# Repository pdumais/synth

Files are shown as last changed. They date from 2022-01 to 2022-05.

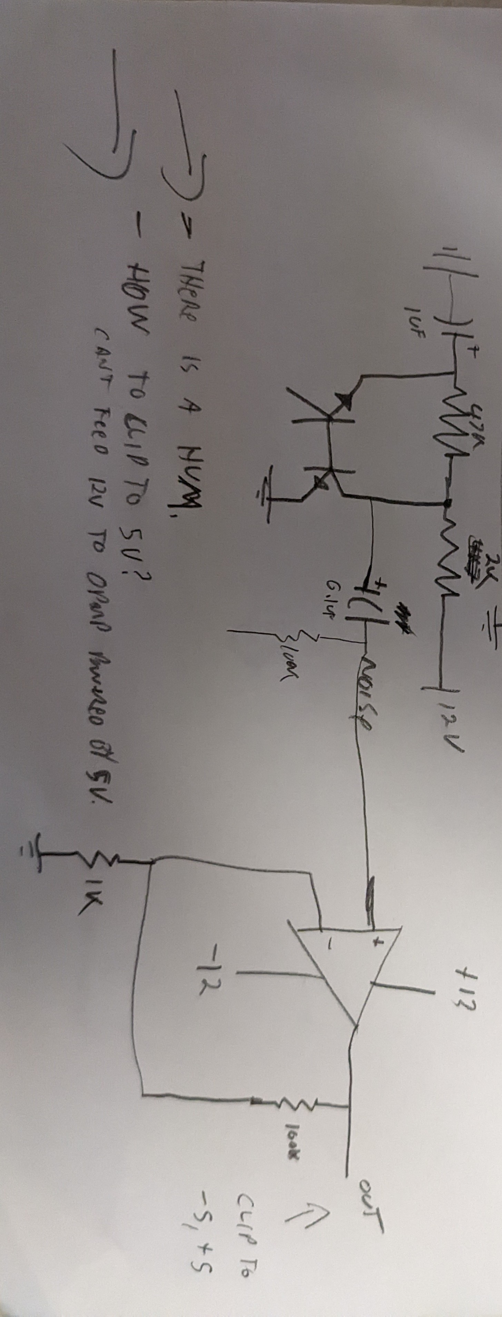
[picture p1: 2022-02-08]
modules/noise/design.jpg

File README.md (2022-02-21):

# Modular Synthesizer

# Design
- 5V system, but requires +12,-12 rails for modules using opamps
- uses computer PSU
- 2 signal paths:
    1) The audio signal. -5 - +5V. 
    2) Control Voltages. They work on unipolar 5V.

# Current modules
- [dual VCO and quad LFO. Square only](modules/osc)
- [LFO shaper: to convert square to trianble/sine or anything in between](modules/waveshaper)
- [Sequencer](modules/sequencer)
- [Clock](modules/clock)
- [Clock Divider](modules/divider)
- [Voltage Controlled Resistors](modules/digipot)
- [Midi2CV](modules/midi2cv)
- [Noise Generator](modules/noise)
- [4 Channel VCA](modules/vca)
- [4 stage VCF](modules/vcf)

# Known issues
- Power filtering
    The oscilloscope shows that the -5 and +5 rails oscillate at an amplitude of 0.4v. The wave has a period of 500ns.
    That's 2mhz. 
    For the CV path, this gets filtered out by the sampling rate of the ADC, so no need to do anything about it. When CV
    is used with analog, it wouldn't be audible anyway.

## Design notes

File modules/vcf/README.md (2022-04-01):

Based on the as3320.

- The range for cutoff frequency CV is +-6V. What does that relate to?
    18mV per octave. they say to use a range from -25 to 155 
    this is a range of 180mV, so 10 octaves. if we stay above 0, we loose
    the last 1.5 octave since increasing voltage lowers the.cutoff

    the 100k and 1.8k resistors on the cv input in the datasheet are a divider
    to drop 10v down to 180mV. I need to adapt this for 5v

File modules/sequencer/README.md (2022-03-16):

# UPDATE
This turns out to be a not so good design.
The stepper and the binary counter are out of sink, so the step number being displayed is not accurate. I suspect
that this is happening because of a difference in startup time betewen both chips, so one chip misses
a clock while the other has processed one already.

But the sequencing part of it does work. So It's a good prototype.

# Design
This is a 8 step sequencer based on the 4017 counter. 

The 4017's Q1 to Q8 outputs go through 8 optentiometers which are all connected to unity gain opamp. The opamp is used to limit the current draw from the system after going out on the CV output

I had a lot of help from this thread: https://www.modwiggler.com/forum/viewtopic.php?t=258437
I'm not sure why having all pots connected together with a 100K resistor doesn't create a voltage divider. It used to create
on and it was a problem. But by connecting everything the the inverting amplifier at the end, it solved that problem. 
At the time of writing this, I don't understand why.

What I didn't like about popular designs that I saw, was that they were all using diodes. The voltage drop of the diode would 
affect the CV by a great margin IMO. With my design, I don't get any voltage drops so CV should be quite accurate. 

## Keeping it simple
As I was designing this module, I realized how many more features I could add to it but it would become increasingly difficult and
more expensive to do so. I realized that I would be much better off to build it with a microcontroller instead. But I decided
to keep using the 4017 because it was an interesting design. 
These are the things I would've liked to do, but decided to hold off until I build a full digital sequencer. The following list 
is more like personal notes so that I can remember later why I didn't implement those.
- A pause button: This sounds simple because all I have to do is inhibit the clock on the 4017 and on the 4163. But both chips
  expect a high and low signal respectively. So I would need a NOT gate for one of them. But then I also need to inhibit the clock
  out of the gate and actually keep that signal high. Instead of using a NOT gate on one of the ic, I could simply cut the clock source.
  but then I would need to tie both ic's clk pins to ground. If I leave it high, I risk creating a rising edge so the pause would 
  force a move to the next step and then pause. So I need to ground the clock signal for the whole circuit, but raise the gate signal.
  it's getting a bit complicated
- Randomizer:To be able to randomly shuffle steps. That's just not something you can do with the 4017.
- variable step length: it would be possible to create the circuitry to manipulate the clock entering the 4017 and multiply/divide 
  for every step. But that's a lot more components to add and becomes more expensive. This is something that is just easier with a 
  microcontroller

## 74163 binary counter
NOTE: This is no longer in the design. Because the 74163 starts with all outputs high and goes to 0 after the first clock
      That's out of sync with the 4017. So I removed that. It could've worked with the 74161 maybe.

The 74163 (4 bit binary counter) is used to control the daisy chaining. QD will be low for the first 8 clocks and then high 
for the next 8 clocks. This is used to control which of the 2 sequencers are active when daisy chained. there are 6 pins that 
require a jumper to control the daisy-chain operation 
    - A jumper between pin 1&2 will make the 4017 active  (by controlling the vcc line) when 4163.QD is high, 
      so during steps 9-16. This is the setting required for the second sequencer
    - A jumper between pin 3&4 will make the 4017 active  (by controlling the vcc line) when 4163.QD is 
      low, so during steps 1-8. This is the setting required for the first sequencer
    - A jumper between pin 5&6 will make the 4017 active  (by controlling the vcc line) all the time, 
      bypassing the 4163 logic. This is the setting required when running a standalone sequencer (8 steps only)
 
Note that both sequencers run their own 4163, so it is possible to configure them in a conflicting manner.

When daisy-chaining, a cable needs to be connected between both sequencers so that:
    - the reset line is connected between both sequencers so that pressing the reset button will act on both sequencers
    - the enable line is connected between both sequencers so that pressing the start/stop button will act on both sequencers

## Gate
The gate signal is fed to a monostable multivibrator that generates a gate signal at the same frequency than the input clock. The pulse width cn be adjusted
beteen 160ms to 1.8s through a 10k potentionmeter

## Inputs / Outputs
### Inputs
    - Clock in
    - Buttons to shorten the sequence to 2 or 4 steps. 
    - Power: +12, -12, +5, Ground 
    - 8 pins for potentiometers wipers, 8 pins for their input voltage from the 4017, 1 pin for their ground
### Outputs
    - CV
    - Gate

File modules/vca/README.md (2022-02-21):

# Voltage Controlled Amplifier

This is based on the AS2164 ic.
    - Unity gain at 5V and -80dB at 0V

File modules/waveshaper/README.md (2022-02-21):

# Wave shaper
Converts a square wave to a triangle or sine or anything in between
Only works for LFOs (below 25hz)
Requires 4 variable resistances (4-gang potentiometer, or digipots)
    Adjusting the resistance will adjust the shape of the wave. 
    If the frequency changes, the shape needs to be reajusted everytime

Can work with audio unipolar signal too. Using a 1uF capacitor with a 10k pot, I we get a sine:
    at 20hz with 10 kOhms
    at 2khz with 100 Ohms
    at 10khz with 20 Ohms

# Inputs
- signal
- 4 variable resistors

# Outputs
- signal

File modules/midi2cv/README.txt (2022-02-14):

The board is programmed through the serial port pins with an FTDI cable. Not through the USB port
    There is a FTDI header on the shield

To test with vkeybd:
    vkeybd --addr 24:0
    The address is the combination of client:port as per /proc/asound/seq/clients
    Testing sysex: amidi -p hw:2,0,0 -S "F0 00 00 <d1> <d2> <d3> F7"

software
	sysex:
		Can be tested with: amidi -p hw:2,0,0 -S "F0 00 00 <d1> <d2> <d3> F7"
		Set channel to listen to for pitch CV 1
			d1 = 0x10
			d2 = CV number (0..2)
			d3 = channel (0..16)
		Set channel to listen to for CC CV 1
			d1 = 0x20
			d2 = CC number (0..2)
			d3 = channel (0..16)
		Set CC number to listen to for CC CV 1
			d1 = 0x30
			d2 = CC number (0..2)
			d3 = CC number (0..255)
		Set output clock pulse width 
			d1 = 0x40
			d2 = width in ms. 5..255
	 	Write config to EEPROM	
			d1 = 0x55
			d2 = 0x55
			d3 = 0x55

hardware
    panel-mount din5
    ftdi programmer

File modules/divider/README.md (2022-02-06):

# Divider
This modules takes a clock input and outputs a version of the same clock divided by 8. So 8hz becomes 1hz.
Square wave only. 5v

There is also a Gate output that can be configured with a different pulse width. The jumpers on on 14pin headers
can be connected in a way to generate a 1/8 pulse width, 2/8 pulse width ... to 7/8 pulse width.
For example, if jumpers are set on 1&2, 3&4, 5&6 and an input clock of 8hz is fed in, the gate will output a 1hz clock
where the first 3/8 of the cycle will be high, and the last 5/8 will be low.

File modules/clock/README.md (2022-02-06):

# Clock module
A rotary encoder connected to the module will set the clock to a BPM from 30 to 240. 
1 square wave output on the CLK pin, and another one, 8 times faster, on the clk8 output.

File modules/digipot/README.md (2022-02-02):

This is a CV to resistance converter. It takes a CV signal of 0-5V and sets 8 digital resistors to that value

- CV input is read through a 10bit ADC but digipots are 8 bits.
- each resistor can be configured from 0 to 10k in 39 Ohm increments

- NOTE: This board has not been tested yet. Need to:
    print it and check if all component fits
    make sure pins for all chips are properly connected

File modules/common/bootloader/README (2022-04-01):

Burning bootloader:
    connect stk500 and chip each on their own power supply. Leave the VCC pin disconnected from the ISP header
    
    avrdude  -c stk500 -pm1284p -P /dev/ttyUSB9 -b115200 -B300 -U lfuse:w:0xF7:m -U hfuse:w:0xDE:m
    avrdude  -c stk500 -pm1284p -P /dev/ttyUSB9 -b115200 -B300 -U flash:w:optiboot_atmega1284p.hex:i

The, using FTDI:
avrdude -vvv -pm1284p -P /dev/ttyUSB10 -carduino -b115200 -U flash:w:firmware.hex:i

    avrdude  -c stk500 -pm32 -P /dev/ttyUSB9 -b115200 -B300 -U lfuse:w:0xA4:m -U hfuse:w:0x90:m
    avrdude  -c stk500 -pm32 -P /dev/ttyUSB9 -b115200 -B300 -U flash:w:optiboot_flash_atmega32_UART0_115200_8000000L_B0.hex:i

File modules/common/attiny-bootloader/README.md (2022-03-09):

Optiboot Bootloader
This core includes an Optiboot bootloader for the ATtiny84/44, operating using software serial at 19200 baud - the software serial uses the AIN0 and AIN1 pins (see UART section below). The bootloader uses 640b of space, leaving 3456 or7552b available for user code. In order to work on the 84, which does not have hardware bootloader support (hence no BOOTRST functionality), "Virtual Boot" is used. This works around this limitation by rewriting the vector table of the sketch as it's uploaded - the reset vector gets pointed at the start of the bootloader, while the EE_RDY vector gets pointed to the start of the application.

Programming the ATtiny84/44 via ISP without the bootloader is fully supported; the 24 is supported only for ISP programming

Wiring for uploading with optiboot
    Gnd of serial adapter to Gnd of target
    Vcc of serial adapter to Gnd of target (many adapters have a switch to select the voltage)
    Tx of serial adapter to Rx of target
    Rx of serial adapter to Tx of target
    DTR of serial adapter to DTR of target, or if using self-build board, the other side of the 0.1uF autoreset capacitor

Wiring for ISP
    Vcc of programmer to Vcc of target
    Gnd of programmer to Gnd of target
    SCK of programmer (pin 13 on Uno/Nano/ProMini) to SCK of target
    MISO of programmer (pin 12 on Uno/Nano/ProMini) to MISO of target
    MOSI of programmer (pin 11 on Uno/Nano/ProMini) to MOSI of target

avrdude  -c stk500 -v -v -pt44 -P /dev/ttyUSB10 -B8 -U lfuse:w:0xE2:m -U hfuse:w:0xDC:m -U efuse:w:0xFE:m
avrdude  -c stk500 -v -v -pt44 -P /dev/ttyUSB10 -B8 -U flash:w:optiboot_attiny44_8000000L.hex:i

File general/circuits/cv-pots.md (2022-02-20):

The first circuit in the diagram can be used to to mix a CV with a potentiometer value and attenuate the result.
This is useful when wanting to use CV and knob at the same time.

The second circuit is used to disable the potentiometer when the CV signal is connected. The resistor is used to protect
the circuit when the jack is being plugged in and the pot is at 0%. There would be a small time when the top would touch
the switch and the signal would flow to the potentiometer.

The third circuit creates an average of both inputs. So the following can happen:
	pot at 0v, CV at 0v: 0v
	pot at 0v, CV at 5v: 2.5v
	pot at 5v, CV at 0v: 2.5v
	pot at 5v, CV at 5v: 5v

So connecting the jack would only allow a partial swing over the base potentiometer value.
It is possible to change the values of the resistors to change the weight of each line. For example, if
the CV resistor is twice as high as the POT, then the POT will have a larger range of operation. it could
then be useful to have 2 pots instead of the resistor and we can control the gain of each input

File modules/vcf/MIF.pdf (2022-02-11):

H

# The Multiple Identity Filter™, Part I

ERE IS A FILTER STRUCTURE that uses only three ICs, has no commercially available equivalent, is only slightly more costly than standard filter modules that do a lot less, and is amazingly versatile. How versatile? Here are some of the responses obtainable with this module:
Lowpass: Choice of 24 18 12 or 6dB/octave slope; includes voltage-controlled (VC) resonance option in 24dB/octave mode. Highpass: Choice of 24, 18, 12, or 6dB/octave slope; includes VC resonance option in 24dB/octave mode.
Phase shifter (allpass): Single or dual notch response. VC resonance option in dual notch mode.
Maximum rolloff lowpass: Similar to 24dB/octave lowpass, but with faster rolloff. A typical application would be getting rid of clock feedthrough from analog delay line outputs.
Notch filter: Choice of broad or sharp notch response. Bandpass: Choice of sharp or broad bandpass response. Lowpass plus notch: Fig. 1 shows the response curve for this type of filter.
Highpass plus notch: Another new type of response. See Fig. 2.
Since this module can assume the identity of many other filter structures, the term “Multiple Identity Filter” (MIF for short) seems very appropriate. But there's still more; it can act as a stand-alone signal phaser, and can put different filter blocks in parallel for highly unusual responses (for example, you could have a I2dB/octave lowpass filter in parallel with a single notch phase shifter, or you could parallel four phase shift sections). There's even a straight channel option with switchable polarity (more on this later). And it's also a sine wave oscillator....
Sound incredible? Well, I still haven't discovered all the possible sounds obtainable from this module, so I don't think you'll get tired of it too easily. You do pay a price for this versatility, the time required to learn how to use the device to best advantage. However, you can always treat the thing like a standard lowpass filter, and learn about the many extras later on at your own pace.
About the circuit. The MIF is based on the CEM3320, a new 4-pole filter IC from Curtis Electromusic Specialties [2900 Mauricia Ave., Santa Clara, CA 950511]; but note that the MIF structure is also equally applicable (with some minor design changes) to the SSM2040 filter IC. The CEM3320 contains four 6dB/octave filter blocks, along with a resonance VCA to give voltage-controlled resonance. There is nothing new about configuring different filter sections to give different responses (see the CEM3320 data sheet, the SSM2040 data sheet and applications notes, and the article “Blacet ‘Phasefilter’ Review” in Device newsletter, Vol. 1, No. 6 [Box C, Carmichael, CA 95608]), but the way in which it is done here is unique. Coupling these programmable filters with switchable, series/parallel patching that's integral to the module is the key to giving the MIF its unprecedented versatility.
Filter Block Characteristics. Fig. 3 shows the MIF's block diagram. Each filter section has two switches that program the response of the filter (highpass, lowpass, allpass, or disabled). Each filter block also has a switch to choose between two different timing caps, placed a decade apart. This allows for unusual slopes, changing the resonant frequencies of filters connected in parallel, and so on.
Series/Parallel Switching. The series/parallel switching scheme has been previously described elsewhere (“Generalized Series/Parallel Switching” in Device, Vol. 1, No. 7). With all three switches in the S position, the four filter blocks are in series. With the switches in the P position, all four blocks are in parallel. Fig. 4 shows some possible configurations, along with the switch settings required to produce these results. Note that when the input of any filter connects to the output of the input buffer (parallel mode), then the output of the preceding filter stage connects to the output mixer. I realize that the switchable patch scheme may be confusing at first—but trace the circuit through for various settings of S1, S2, and S3; it should all make sense after about 15 minutes of checking it out.
Resonance Cell. A resonance VCA connects from the output of the last filter section to the input of the first filter section, and is therefore most usable when all four filters are in series. It has a panel control that sets the resonance, and a control voltage input jack. Plugging into the jack disables the from panel control and allows for a 0 to +10V control of resonance (with high resonance, the filter changes identity to a sine wave oscillator). Input Buffer. This section conditions signals going to the filter, and has three inputs. One input is noninverting; one is noninverting and includes an attenuator; the remaining input is inverting. Phase compatibility with parallel filters is very important, and having a choice of inputs allows you to choose your phase.
Straight Channel. A fader allows you to mix unfiltered sound in with the filtered sound. A phase switcher in the straight signal path allows you to choose the straight signal phase.
Control Voltage Amp. This has two inputs that follow the industry standard, 0 to +10V, exponential response control curve. One input includes an attenuator, the other does not. There is also an initial frequency control.
Part I Conclusion. I realize the all this may be confusing— after all, programmable filter structures, integral switchable patching, and optional phaser response are not part of the “standard” synthesizer lexicon (but if I get my way, they will be soon!). I do think that after the conclusion of this series, though, everything will fall right into place. In any event, I hope I've managed to convey some of my excitement for this device, and I hope you're excited about it too. Next month, it's construction time.

CONTEMPORARY KEYBOARD/NOVEMBER 1979

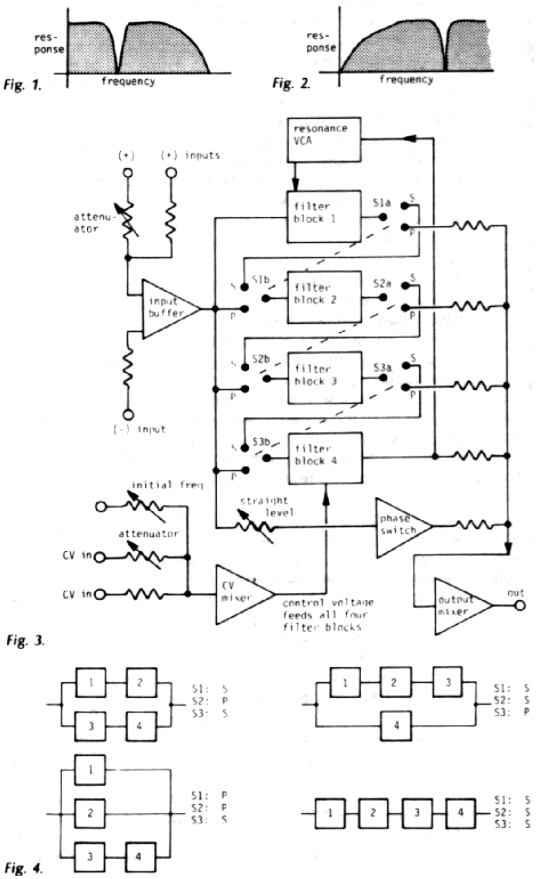
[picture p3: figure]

T

# Multiple Identity Filter™, Part II

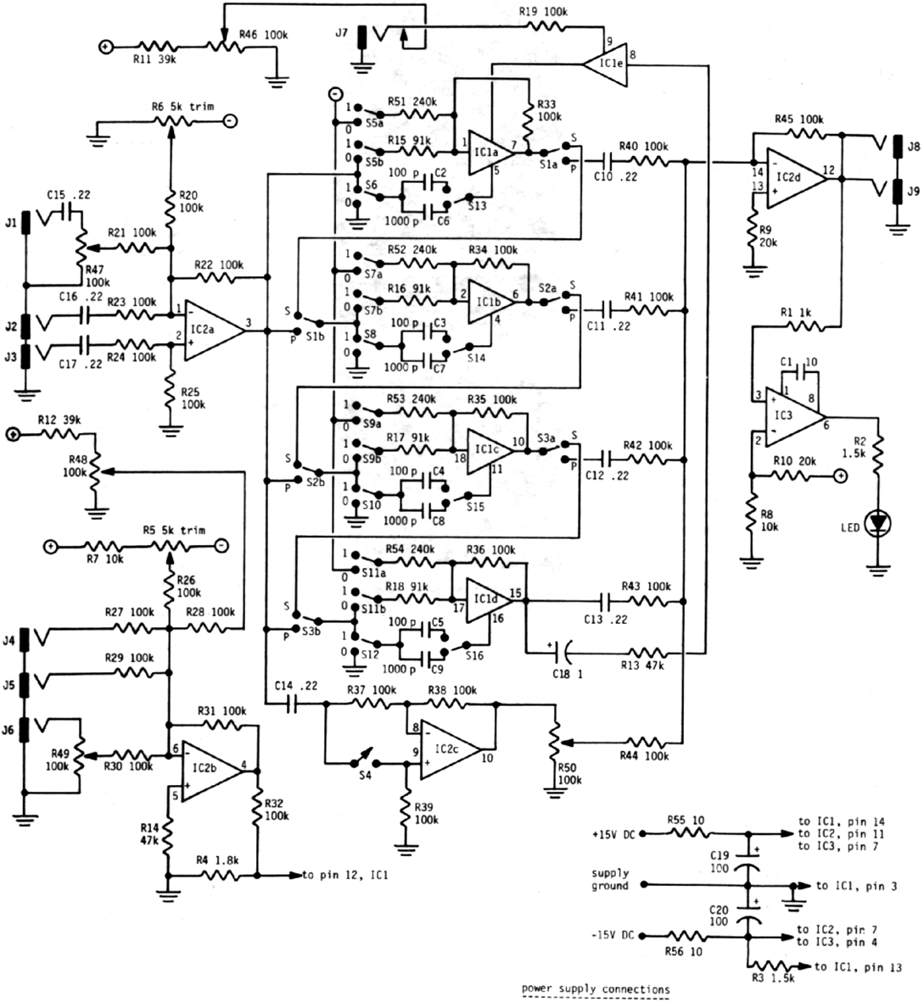
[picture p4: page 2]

DECEMBER 1979/CONTEMPORARY XEYBOARD

HIS MONTH, THERE'S ONLY ROOM for the schematic and the annotated parts list. Next month, we'll give construction tips and calibration procedures. Please do not attempt to wire this beast up until then, no matter how experienced you are; the panel layout and switch orientations are just as important as the circuitry, and you’ll want to wait until that information is presented before you actually start building. We’ll have some photos of a prototype built from the parts kit, which should also help in building this module.

DECEMBER 1979/CONTEMPORARY XEYBOARD

CRAIG ANDERTON | PARTS LIST
Resistors (all are 5%, 1/4 watt units except for the pots)
R1 | 1k
R2,R3 | 1.5k
R4 | 1.8k resistor. For maximum temperature
stability use a
+3300 ppm temperature compensated resistor (Tel Labs Q81). To use the 2k tempco resistor offered by the Electronotes parts service, change R32 to 110k. You can always wire in a regular resistor first, and change it over later to the temperature compensated kind.
R5 | 5k trimpot. Adjusts control voltage (CV) amp
offset. See calibration instructions next month.
R6 | 5k trimpot. Adjusts output of 1C2a to +6.5V
DC with no
input signal. See calibration instructions next month.
R7,R8 | 10k
R9,R10 | 20k
R11,R12 | 39k
R13,R14 | 47k
R15-Rl8 | 91k
R19-R45 | 100k
R46 | 100k linear pot. Controls resonance when J7
is not used for an external control voltage.
R47 | 100k audio or linear taper pot. Use to
attenuate audio
input signal If clipping indicator (LED) starts to glow.
R48 | 100k linear pot. Sets initial filter frequency
(offset).
R49 | 100k linear pot. Attenuates CV source
plugged into J6.
R50 | 100k audio or Iinear taper pot. Controls level
of straight audio signal.
R51-R54 | 240k
R55,R56 | 10 ohms
Capacitors (all should be rated to work at 15V or more)
C1 | 10 to 20pF ceramic disc
C2-C5 | 100pF; use polystyrene cap for best stability.
C6-C9 | 1000pF; use polystyrene cap for best stability.
C10-C17 | .22µF mylar or disc
C18 | 1µF tantalum or electrolytic
C19,C20 | 100µF electrolytic

Semiconductors
IC1 | Curtis CEM3320 [Curtis Electromusic Specialties, 2900 Mauricia Ave., Santa Clara, CA 95051. Hobby market distributor: PAIA Electronics, 102D W. Wilshire Blvd, Oklahoma City, OK 73116. Cost is $8.95 in single quantities; add $1 postage/handling].
IC2 | RC4136, XR4136, or equivalent quad low- noise op amp.
IC3 | LM748 or LM301 uncompensated op amp.
LED | Any red LED will do just fine.
Mechanical parts
J1 | 1/4" mono open-circuit phone jack. Accepts an audio input signal that may be attenuated by R47.
J2,J3 | 1/4" mono open-circuit phone jacks. These jacks accept additional audio input signals if desired.
J4,J5 | 1/4" mono open-circuit phone jacks. These jacks accept any 0 to +10V control voltage to control the filter frequency.
J6 | 1/4" mono open-circuit phone jack. Accepts a 0 to +10 CV that may also be attenuated by R49.
J7 | 1/4" mono closed-circuit phone jack. Accepts a 0 to +10 CV to control the filter resonance, and simultaneously disables R46.
J8,J9 | 1/4" mono open-circuit phone jacks. These jacks provide dual audio outputs from the filter.
S1-S3 | DPDT switches that provide series/parallel switching for the various filter sections.
S4 | SPST switch. Changes phase of straight channel; when shorted, phase is noninverting. When open, phase is inverting.
S5,S7,S9,S11 | DPDT switches, used in conjunction with S6, S8, S10, and S12 to program the responses of the various filter blocks.

S6,S8,S10,S12 SPDT switches, used in conjunction with the
| above
| switches to program the responses of the various filter blocks.
S13-S16 | SPDT switches. These select the timing capacitor for each filter section.
IC sockets | You will need one 18pin socket, one 14pin socket, and one 8pin socket.

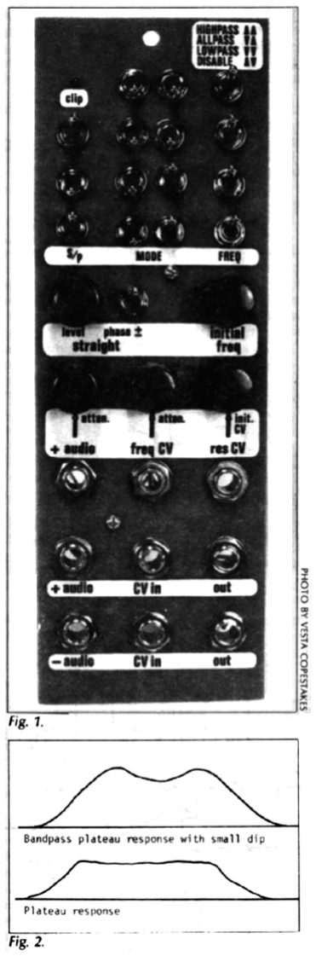
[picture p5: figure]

I

CONTEMPORARY KEYBOARD/JANUARY 1979

# Multiple Identity Filter™, Part III

F YOU’VE READ Parts I and II of this series, you’ll be itching to get into the construction of the Multiple Identity Filter (MIF), which I gave the schematic of last month. So let’s get to it. Construction. The photo in fig. 1 shows a prototype module I built on a 9" x 3" Plexiglass panel. The control layout is as follows: The upper row; left to right, comprises the clipping indicator LED, S5, S6, and S13. The row of switches below is S1, S7, S8, and S14, again left to right—in fact, we’ll just assume that all locations are given from left to right to minimize repetition. The next lower row of switches is S2, S9, S10, and S15; and the bottom row of switches is S3, S11, S12, and S16. The top row of controls is R50, S4, and R48, while the bottom control row is R47, R49, and R46. The top row of jacks is J1, J6, and J7; the row below, J2, J4, and 18; the bottom row, J3, J5, and J9. Switches S1-S3 should be oriented during construction so that toggling them upwards puts them in the “S” position (see last month's schematic), and switches S5-S12 should be oriented so that toggling them upwards puts them in the “1” position. S13-S16 should be oriented so that the upwards position selects the 100pF timing capacitor, while the downwards position selects the 1000pF timing capacitor.
By the way, a parts kit for this module will be available soon from PAIA Electronics, although pricing and delivery are not firmed up at this time (columns are prepared months in advance of publication dates).
Calibration. This process isn't difficult as long as you have a voltmeter. Connect one probe to pin 3 of IC2, and the other probe to pin 10 of IC1; then set the range selector switch for about a 0 to 5V DC. After applying power and setting the initial frequency control halfway, adjust R6 for a 0-volt reading on the meter. You might find adjustment is a bit less critical if you change R20 to a 220k resistor instead of the 100k value given last month, although in any case the module should be calibratable.
There are a number of ways to calibrate R5, all of which are difficult to write down on paper but obvious when you have the unit sitting in front of you. The basic idea is to adjust this control so that a 0V control voltage (CV) gives the lowest desired filter frequency, and a +10 CV gives the highest desired frequency. One calibration procedure for R5 is to feed a low-frequency (approx. 80Hz) square wave into J1, and patch up the MIF for a basic 24dB/ octave lowpass configuration (see patch chart). Vary the initial frequency from lowest to highest frequency (0 to +10V), and leave it at the highest frequency position. Set R5 to the extreme of rotation that gives the most high frequencies. Now slowly rotate R5 towards the other extreme until you hear just the slightest reduction in high frequency content. Leave R5 right there, and the MIF is calibrated.
Applications. Ask an engineeringminded synthesist what a filter does. and that person will probably tell you about how it alters the waveform of a VCO fed into its input, and how it can change the harmonic structure of a complex waveform. However, ask a recording engineer what a filter does, and the answer will be that filters are put together in systems to make up equalizers that alter frequency response, correct for response anomalies, and so on. This difference in operating philosophy has meant that most filters designed for synthesizers perform poorly with program material or when
processing | acoustic | instruments,
whereas studio equalizers work well for processing but are generally not voltage-controlled and are used more for subtle corrections than for special effects. The strength of the MIF is that it feels at home in both roles; hopefully, synthesists will get into more subtle types of sound with this module, and conversely, I hope that recording enthusiasts find out that having dynamic—rather than static—equalization can do some really amazing things.
If you know how to use a scope and a signal generator, looking at the MIF output for various controls will show you a tremendous amount about how this thing works,. Of course, your ears will tell you the most, but if you can analyze what the MIF is doing electrically, you'll know how to apply it to solve specific response problems that crop up.
There are only a few rules to consider when using the filter. First, when sections are switched in parallel, you’ll have to back off on the input signal to avoid clipping (the clipping indicator I should show this condition). Next, the voltage-controlled resonance feature may or may not do something interesting; twist the initial resonance knob and if you get a good sound, great. If nothing happens, that simply means you’re using a patch where the resonance cell is inoperative. Another point to remember is that there are many, many responses of which this thing is capable, and it’s also possible to duplicate the same response with different patches (for example, there are four or five ways to create a notch response). Finally, there are some patches where you may have to boost the input signal a bit if you're doing a particularly strange patch.
Final Comments. The mini-manual on the opposite page should get you started on the road towards using the MIF in a predictable and efficient way; remember, it’s going to take you some time to master it. If you discover any particularly good patches or applications with this beast (e.g., “The highpass plus notch response works great with electric pianos”), write me c/o CK and I’ll pass these ideas along. And the future? Why, using individual voltage-controlled filters for each MIF section in conjunction with microprocessor control and a little memory.... But in the meantime. I'll try to master the module I have now. Multiple Identity Filter Mini-Manual The following diagrams show the orientation of the switches in the switching matrix (S1-S3, S5-S16) for various filter modes; U means up, D means down. Don’t forget that in most cases, fooling
around | with | the | capacitor | select
switches (S13-S16) will create new responses. Adding in some straight signal, either in phase or out of phase, will create other changes. The designation X means the switch position is irrelevant.

Lowpass, 24dB/octave
DDU
UDDU
UDDU
UDDU
Lowpass, 18dB/octave
DDU
UDDU
UDDU
DUDX
Lowpass, 12dB/octave
DDU
UDDU
DUDX
DUDX
Lowpass, 6dB/octave
DDU
DUDX
DUDX
DUDX

Highpass, 24dB/octave
UUD
UUUD
UUUD
UUUD
Highpass, 18dB/octave
UUD
UUUD
UUUD
DUDX
Highpass, 12dB/octave
UUD
UUUD
DUDX
DUDX
Highpass, 6dB/octave
UUD
DUDX
DUDX
DUDX

Bandpass, 12dB/octave slope DDU
UDDU
UUUD
UUUD
*Add (-) straight signal for inverted (notch) response.
*Add resonance to produce plateau response (see Fig. 2)
Bandpass, 24dB/octave slope UUD
UDDU
DUDX
UUDX
*Add (+) straight signal for inverted (notch) response.
Lopsided bandpass (low frequency slope 6dB/ octave, upper frequency slope 18dB/octave)
DDU
UDDU
UDDU
UUUD
*Add (+) straight signal for inverted response (lopsided notch).
Lopsided bandpass (low frequency slope 18dB/ octave, upper frequency slope 6dB/octave)
DDU
UUUD
UUUD
UUUD
*Add (+) straight signal for inverted response (lopsided notch).

Bandpass Plateau response with small dip (see Fig. 2)
UUD
UDDD
DUUU
UDDU
Highpass plus notch response (also lowpass plus notch)
DUU
UDUU
UDUU
DUDX
*Add in straight signal for HP plus notch. *Add in straight signal for LP plus notch. Allpass, dual notch
DUU
UDUU
UDUU
UDUU
(notches spaced approximately 6:1 apart with respect to frequency)
DUD
UDUU
UDUU
UDUU
(notches spaced approximately 10:1 apart with respect to frequency)
DUU
UDUU
UDUD
UDUD
(notches spaced approximately 16:1 apart with respect to frequency)
*Add in(+) straight signal to create dual notch.
*Add in (-) straight signal to reverse position of peaks and notches.

AlIpass, single notch
DUU
UDUU
DUDX
UUDX
*Add in (+) straight signal to create single notch.
*Add in (-) straight signal to create bandpass response.
Single notch
UUD
UUUU
DDDU
UDDU
(shallow notch—about -6dB) UUU
UUUU
DDDU
UDDU
(deep notch—about 3OdB)

JANUARY 1979/CONTEMPORARY XEYBOARD

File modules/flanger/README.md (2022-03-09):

# Flanger
Based on a 2048 stage BBD.

# Design
```mermaid
graph LR;
    Input-->InputMixer;
    InputMixer-->OutputMixer;
    InputMixer-->InLPF;
    InLPF-->BBD;
    BBD-->OutLPF;
    OutLPF-->OutputMixer;  
    OutLPF-->InputMixer;
```

# Inputs
    Analog controls
        Audio In
        LFO CV: input CV to use as external LFO. Will be ignored unless Rate and Depth are both zero
        Dry/Wet: output Mixer
        trimpot: for the BBD outputs balancing

    uC controls
        Rate: To control the speed of the embeded (in the uC) triangle LFO
        Depth: To control the amplitude of the LFO. 
        Offset: Base value on which the LFO will be added 

# Outputs
    Audio Out

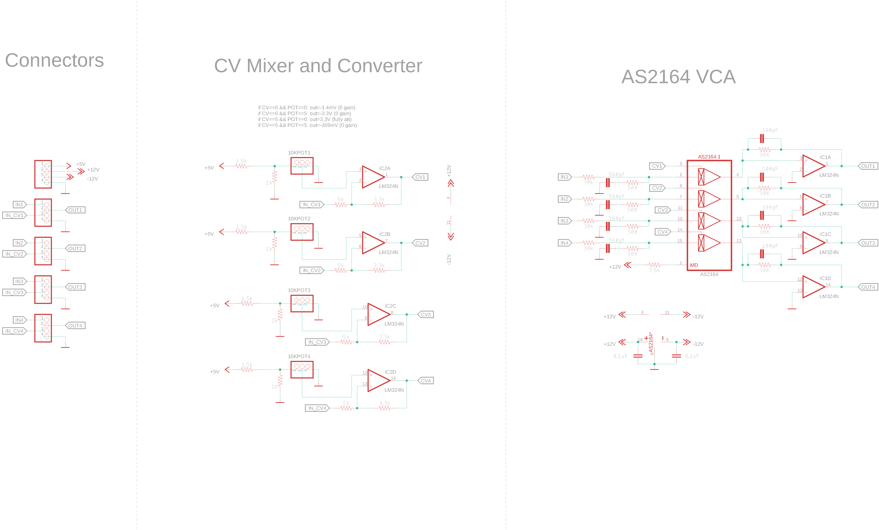
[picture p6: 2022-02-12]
modules/vca/schematic.png

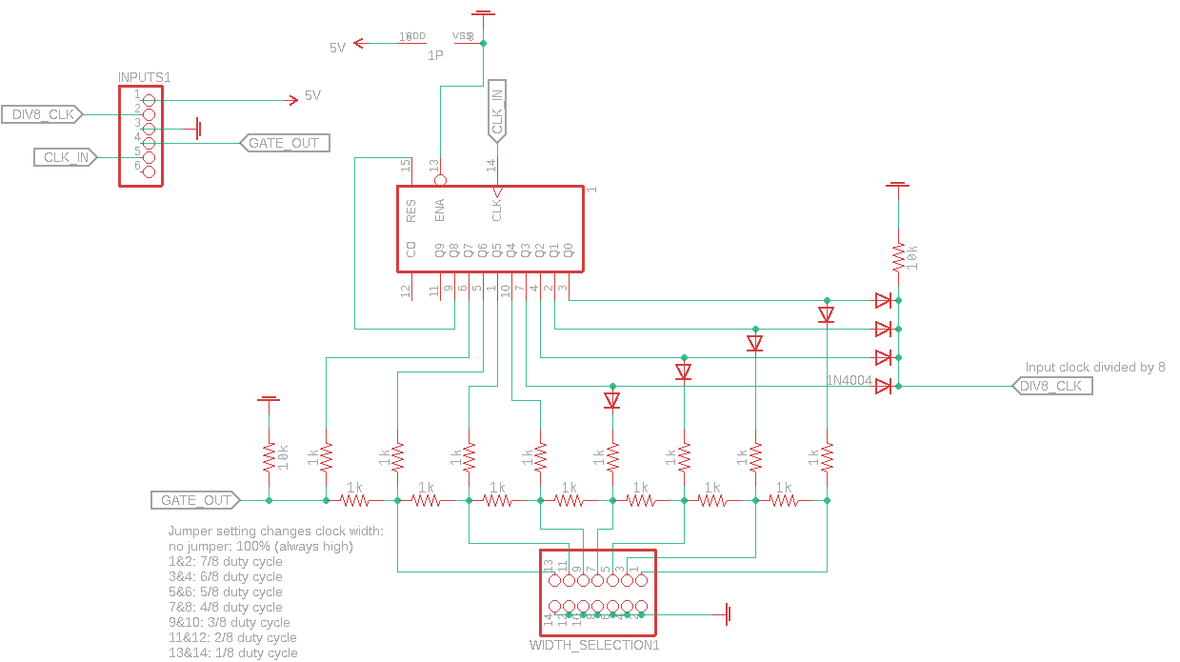
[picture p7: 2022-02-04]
modules/divider/schematic.png

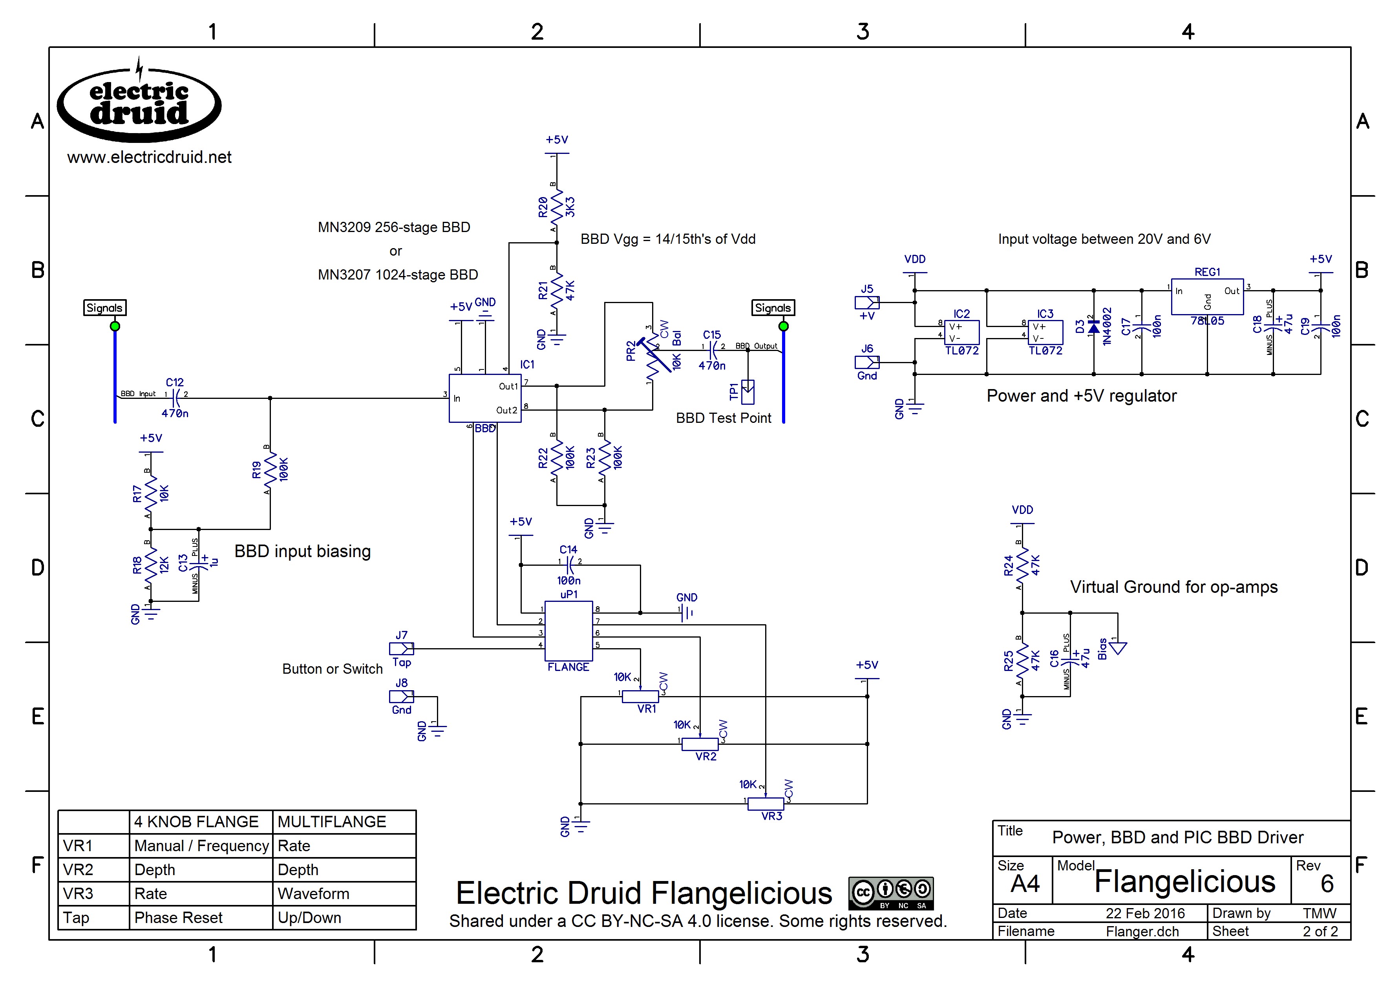
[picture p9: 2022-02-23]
doc/Flangelicious-Pg2.jpg

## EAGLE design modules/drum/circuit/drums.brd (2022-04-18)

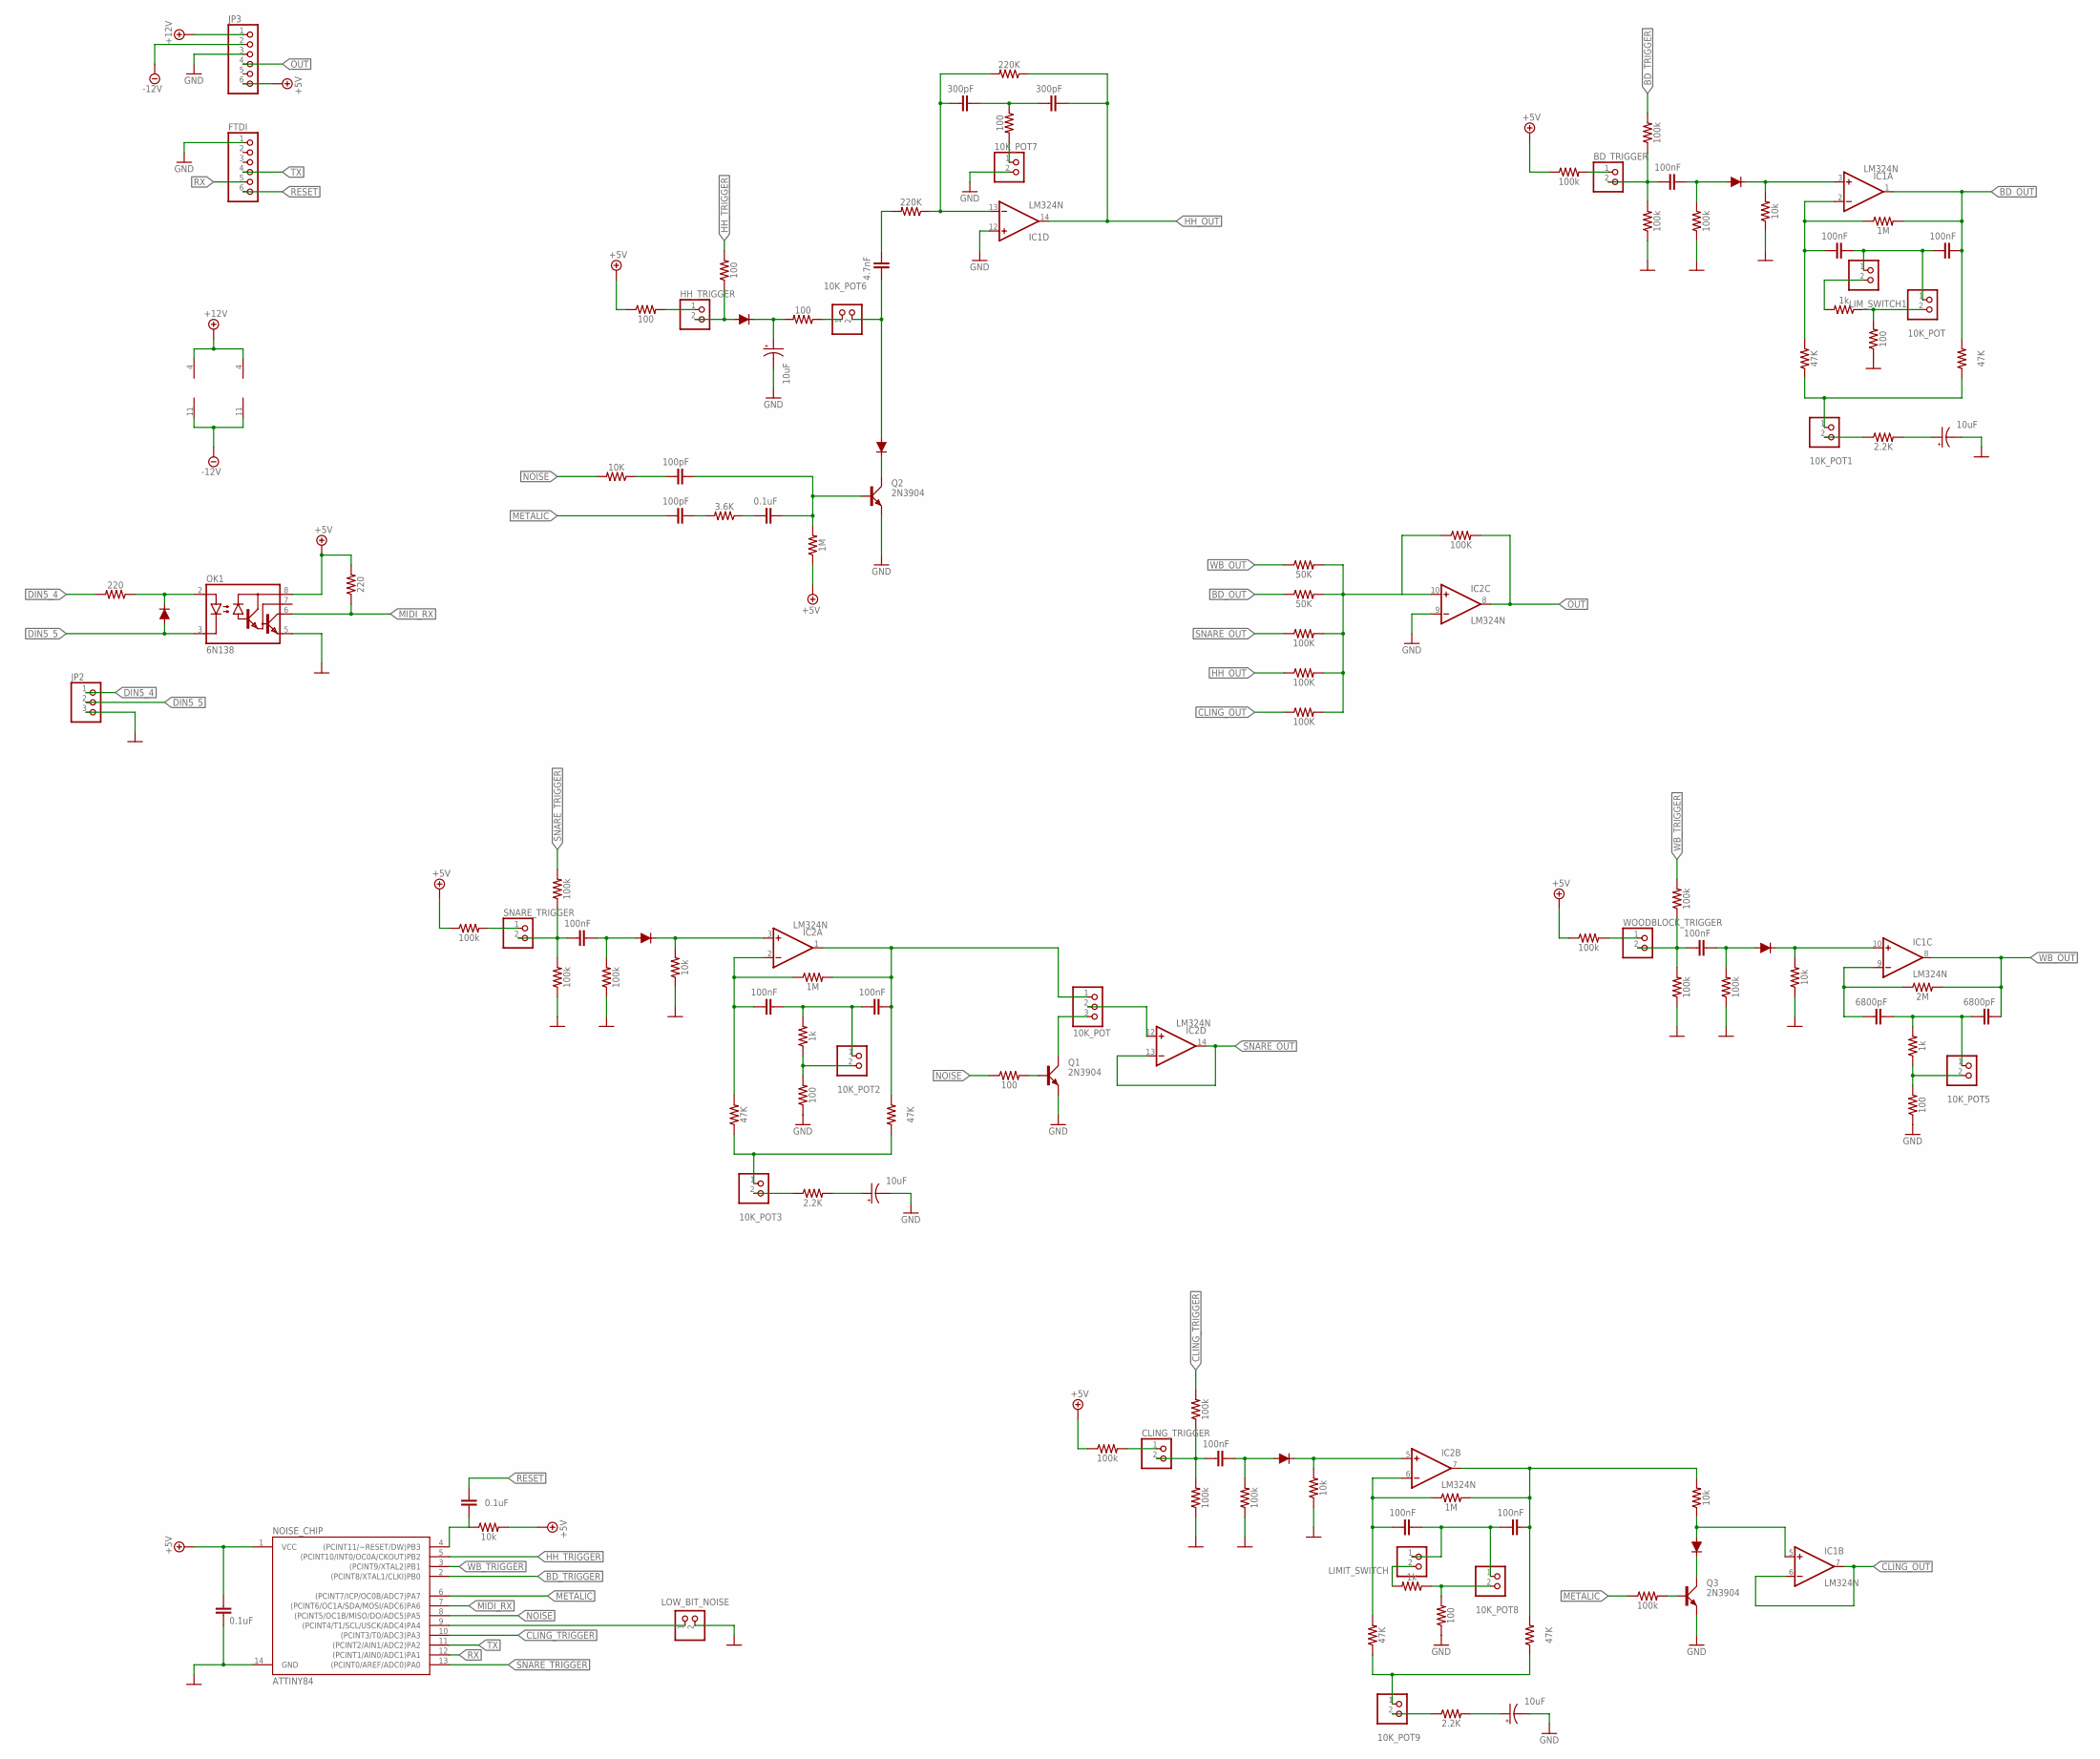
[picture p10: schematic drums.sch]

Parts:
1M: 1M; AXIAL-0.3
1M1, 1M2: 220; AXIAL-0.3
10K_POT, 10K_POT1, 10K_POT2, 10K_POT3, 10K_POT5, 10K_POT6, 10K_POT7, 10K_POT8, 10K_POT9: PINHD-1X2; 1X02
10K_POT4: 10K_POT; 1X03
BD_TRIGGER: PINHD-1X2; 1X02
C1, C4, C12: 0.1uF; C5B3
C2, C3, C6, C7, C18, C19, C20, C21, C22, C24: 100nF; C5B3
C5, C8, C11, C23: 10uF; TT5D11
C9, C10: 6800pF; C5B3
C13, C14: 100pF; C5B3
C15: 4.7nF; C5B3
C16, C17: 300pF; C5B3
CLING_TRIGGER: PINHD-1X2; 1X02
D1, D2, D3, D4, D5, D6, D7, D8: 1A/50V/1.1V; DIODE-1N4001-KIT
FTDI: PINHD-1X6; 1X06
HH_TRIGGER: PINHD-1X2; 1X02
IC1, IC2: LM324N; DIL14
JP2: PINHD-1X3; 1X03
JP3: PINHD-1X6; 1X06
LIMIT_SWITCH: PINHD-1X2; 1X02
LIM_SWITCH1: PINHD-1X2; 1X02
LOW_BIT_NOISE: PINHD-1X2; 1X02
NOISE_CHIP: ATTINY84; DIP14
OK1: 6N138; DIL08
Q1, Q2, Q3: 2N3904; TO92D
R1, R12, R19, R20, R23, R38, R39, R41, R42, R43, R44, R45, R52, R54, R55, R56, R57: 100k; AXIAL-0.3
R2, R22, R25, R40, R53, R59: 10k; AXIAL-0.3
R3, R13, R46: 1M; AXIAL-0.3
R4, R5, R14, R15, R47, R48: 47K; AXIAL-0.3
R6, R16, R27, R49: 1k; AXIAL-0.3
R7, R11, R17, R21, R26, R28, R29, R36, R50: 100; AXIAL-0.3
R8, R18, R51: 2.2K; AXIAL-0.3
R9, R31: 50K; AXIAL-0.3
R10, R30, R37, R58: 100K; AXIAL-0.3
R24: 2M; AXIAL-0.3
R32: 3.6K; AXIAL-0.3
R33: 10K; AXIAL-0.3
R34, R35: 220K; AXIAL-0.3
SNARE_TRIGGER: PINHD-1X2; 1X02
WOODBLOCK_TRIGGER: PINHD-1X2; 1X02

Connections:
10K_POT1: 10K_POT1.1, R4.P$1 (1), R5.P$1 (1)
10K_POT2: 10K_POT3.1, R14.P$1 (1), R15.P$1 (1)
10K_POT3: 10K_POT9.1, R47.P$1 (1), R48.P$1 (1)
+5V: 1M.P$1 (1), 1M1.P$2 (2), C1.1, JP3.6, NOISE_CHIP.1 (VCC), OK1.8 (VCC), R23.P$1 (1), R25.P$2 (2), R29.P$1 (1), R38.P$1 (1), R41.P$1 (1), R54.P$1 (1)
+12V: IC1.4 (V+), IC2.4 (V+), JP3.1
-12V: IC1.11 (V-), IC2.11 (V-), JP3.2
BD_OUT: 10K_POT4.1, C3.2, C7.2, IC1.1 (OUT), IC2.1 (OUT), R3.P$2 (2), R5.P$2 (2), R13.P$2 (2), R15.P$2 (2), R31.P$1 (1)
BD_OUT1: C22.2, IC2.7 (OUT), R46.P$2 (2), R48.P$2 (2), R59.P$2 (2)
BD_TRIGGER: NOISE_CHIP.2 ((PCINT8/XTAL1/CLKI)PB0), R12.P$2 (2)
CLING_OUT: IC1.6 (-IN), IC1.7 (OUT), R58.P$1 (1)
CLING_TRIGGER: NOISE_CHIP.10 ((PCINT3/T0/ADC3)PA3), R57.P$2 (2)
DIN5_4: 1M2.P$2 (2), JP2.1
DIN5_5: D2.A, JP2.2, OK1.3 (C)
GND: 10K_POT7.2, C1.2, C5.-, C8.-, C11.-, C23.-, FTDI.1, IC1.12 (+IN), IC2.9 (-IN), JP2.3, JP3.3, LOW_BIT_NOISE.2, NOISE_CHIP.14 (GND), OK1.5 (GND), Q1.E, Q2.E, Q3.E, R1.P$1 (1), R2.P$1 (1), R7.P$1 (1), R17.P$1 (1), R22.P$1 (1), R28.P$1 (1), R39.P$1 (1), R40.P$1 (1), R42.P$1 (1), R43.P$1 (1), R44.P$1 (1), R45.P$1 (1), R50.P$1 (1), R53.P$1 (1), R55.P$1 (1), R56.P$1 (1)
HH_OUT: C17.2, IC1.14 (OUT), R35.P$1 (1), R37.P$1 (1)
HH_TRIGGER: NOISE_CHIP.5 ((PCINT10/INT0/OC0A/CKOUT)PB2), R11.P$2 (2)
METALIC: C14.1, NOISE_CHIP.6 ((PCINT7/ICP/OC0B/ADC7)PA7), R52.P$1 (1)
MIDI_RX: 1M1.P$1 (1), NOISE_CHIP.7 ((PCINT6/OC1A/SDA/MOSI/ADC6)PA6), OK1.6 (VO)
unnamed: 10K_POT8.1, C21.2, C22.1, LIMIT_SWITCH.1
unnamed: BD_TRIGGER.2, C18.1, R12.P$1 (1), R39.P$2 (2)
unnamed: D1.C, IC1.3 (+IN), R2.P$2 (2)
unnamed: C18.2, D1.A, R1.P$2 (2)
unnamed: BD_TRIGGER.1, R38.P$2 (2)
unnamed: 10K_POT.1, C2.2, C3.1, LIM_SWITCH1.1
unnamed: C2.1, IC1.2 (-IN), R3.P$1 (1), R4.P$2 (2)
unnamed: C21.1, IC2.6 (-IN), R46.P$1 (1), R47.P$2 (2)
unnamed: 10K_POT.2, R6.P$1 (1), R7.P$2 (2)
unnamed: 10K_POT1.2, R8.P$1 (1)
unnamed: C5.+, R8.P$2 (2)
unnamed: 1M2.P$1 (1), D2.C, OK1.2 (A)
unnamed: 10K_POT8.2, R49.P$1 (1), R50.P$2 (2)
unnamed: 10K_POT9.2, R51.P$1 (1)
unnamed: C19.1, R19.P$1 (1), R42.P$2 (2), WOODBLOCK_TRIGGER.2
unnamed: 10K_POT2.1, C6.2, C7.1, R16.P$2 (2)
unnamed: C6.1, IC2.2 (-IN), R13.P$1 (1), R14.P$2 (2)
unnamed: 10K_POT2.2, R16.P$1 (1), R17.P$2 (2)
unnamed: 10K_POT3.2, R18.P$1 (1)
unnamed: C8.+, R18.P$2 (2)
unnamed: C23.+, R51.P$2 (2)
unnamed: Q1.B, R21.P$2 (2)
unnamed: 10K_POT4.3, Q1.C
unnamed: 10K_POT4.2, IC2.12 (+IN)
unnamed: C20.1, R20.P$1 (1), R44.P$2 (2), SNARE_TRIGGER.2
unnamed: D3.C, IC2.3 (+IN), R22.P$2 (2)
unnamed: R23.P$2 (2), SNARE_TRIGGER.1
unnamed: D6.C, IC1.10 (+IN), R40.P$2 (2)
unnamed: 10K_POT5.1, C9.2, C10.1, R27.P$2 (2)
unnamed: C9.1, IC1.9 (-IN), R24.P$1 (1)
unnamed: 10K_POT5.2, R27.P$1 (1), R28.P$2 (2)
unnamed: D4.A, HH_TRIGGER.2, R11.P$1 (1)
unnamed: C11.+, D4.C, R26.P$2 (2)
unnamed: IC2.10 (+IN), R9.P$2 (2), R10.P$2 (2), R30.P$1 (1), R31.P$2 (2), R37.P$2 (2), R58.P$2 (2)
unnamed: 10K_POT6.1, R26.P$1 (1)
unnamed: 10K_POT6.2, C15.1, D5.A
unnamed: C4.2, NOISE_CHIP.4 ((PCINT11/~RESET/DW)PB3), R25.P$1 (1)
unnamed: D5.C, Q2.C
unnamed: C12.1, R32.P$1 (1)
unnamed: 1M.P$2 (2), C12.2, C13.2, Q2.B
unnamed: HH_TRIGGER.1, R29.P$2 (2)
unnamed: C13.1, R33.P$1 (1)
unnamed: C15.2, R34.P$2 (2)
unnamed: C14.2, R32.P$2 (2)
unnamed: 10K_POT7.1, R36.P$2 (2)
unnamed: C16.2, C17.1, R36.P$1 (1)
unnamed: R41.P$2 (2), WOODBLOCK_TRIGGER.1
unnamed: C16.1, IC1.13 (-IN), R34.P$1 (1), R35.P$2 (2)
unnamed: C19.2, D6.A, R43.P$2 (2)
unnamed: C20.2, D3.A, R45.P$2 (2)
unnamed: Q3.B, R52.P$2 (2)
unnamed: D8.C, Q3.C
unnamed: D8.A, IC1.5 (+IN), R59.P$1 (1)
unnamed: C24.1, CLING_TRIGGER.2, R55.P$2 (2), R57.P$1 (1)
unnamed: D7.C, IC2.5 (+IN), R53.P$2 (2)
unnamed: CLING_TRIGGER.1, R54.P$2 (2)
unnamed: C24.2, D7.A, R56.P$2 (2)
unnamed: LIM_SWITCH1.2, R6.P$2 (2)
unnamed: LIMIT_SWITCH.2, R49.P$2 (2)
unnamed: LOW_BIT_NOISE.1, NOISE_CHIP.9 ((PCINT4/T1/SCL/USCK/ADC4)PA4)
NOISE: NOISE_CHIP.8 ((PCINT5/OC1B/MISO/DO/ADC5)PA5), R21.P$1 (1), R33.P$2 (2)
OUT: IC2.8 (OUT), JP3.4, R30.P$2 (2)
RESET: C4.1, FTDI.6
RX: FTDI.5, NOISE_CHIP.12 ((PCINT1/AIN0/ADC1)PA1)
SNARE_OUT: IC2.13 (-IN), IC2.14 (OUT), R10.P$1 (1)
SNARE_TRIGGER: NOISE_CHIP.13 ((PCINT0/AREF/ADC0)PA0), R20.P$2 (2)
TX: FTDI.4, NOISE_CHIP.11 ((PCINT2/AIN1/ADC2)PA2)
WB_OUT: C10.2, IC1.8 (OUT), R9.P$1 (1), R24.P$2 (2)
WB_TRIGGER: NOISE_CHIP.3 ((PCINT9/XTAL2)PB1), R19.P$2 (2)

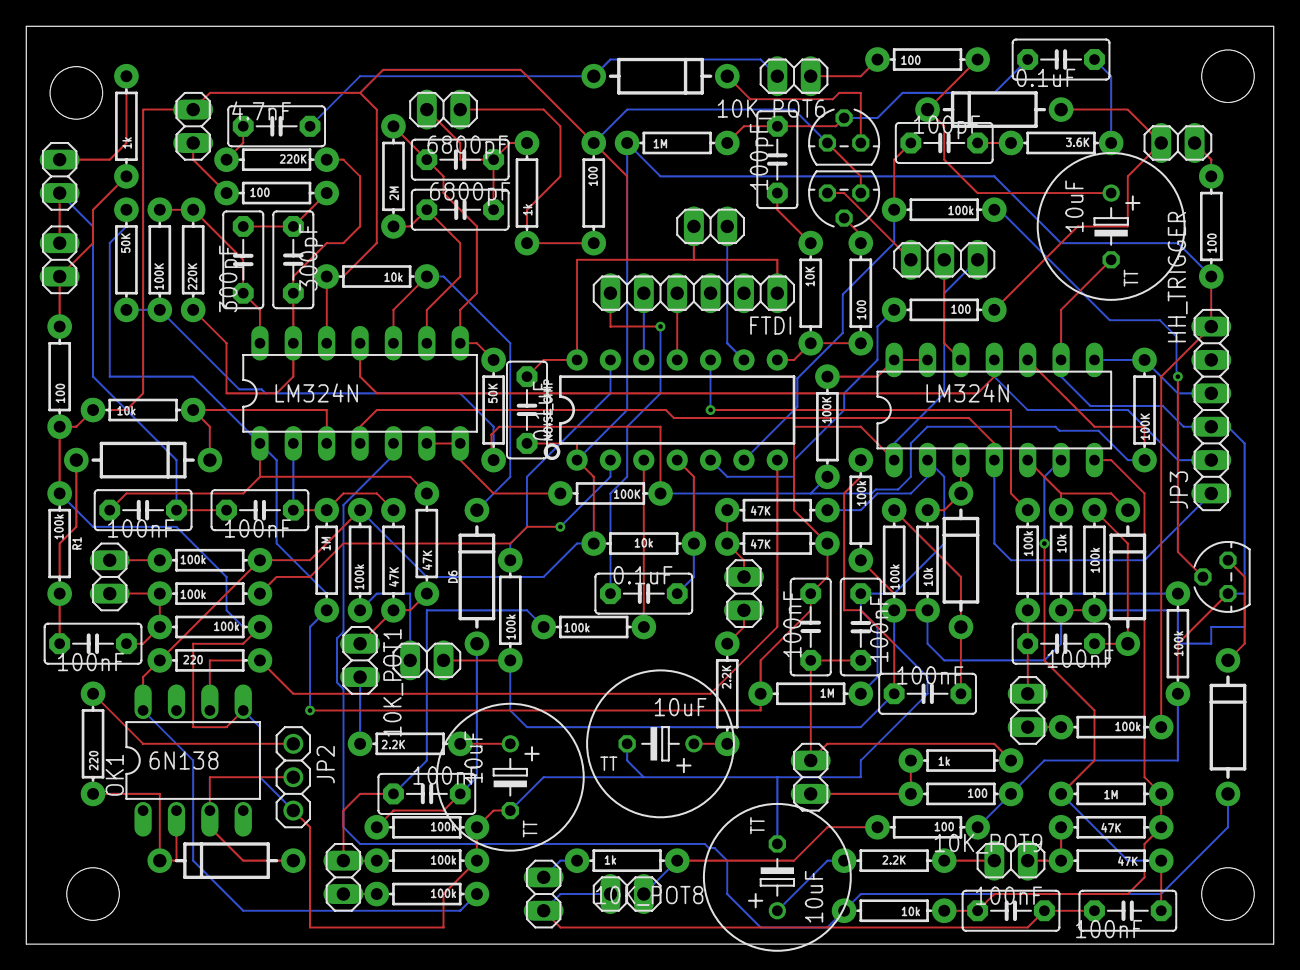
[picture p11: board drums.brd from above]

Board: 2 copper layers, 94.9 x 69.8 mm, 122 parts (0 on the bottom side), 87 nets.

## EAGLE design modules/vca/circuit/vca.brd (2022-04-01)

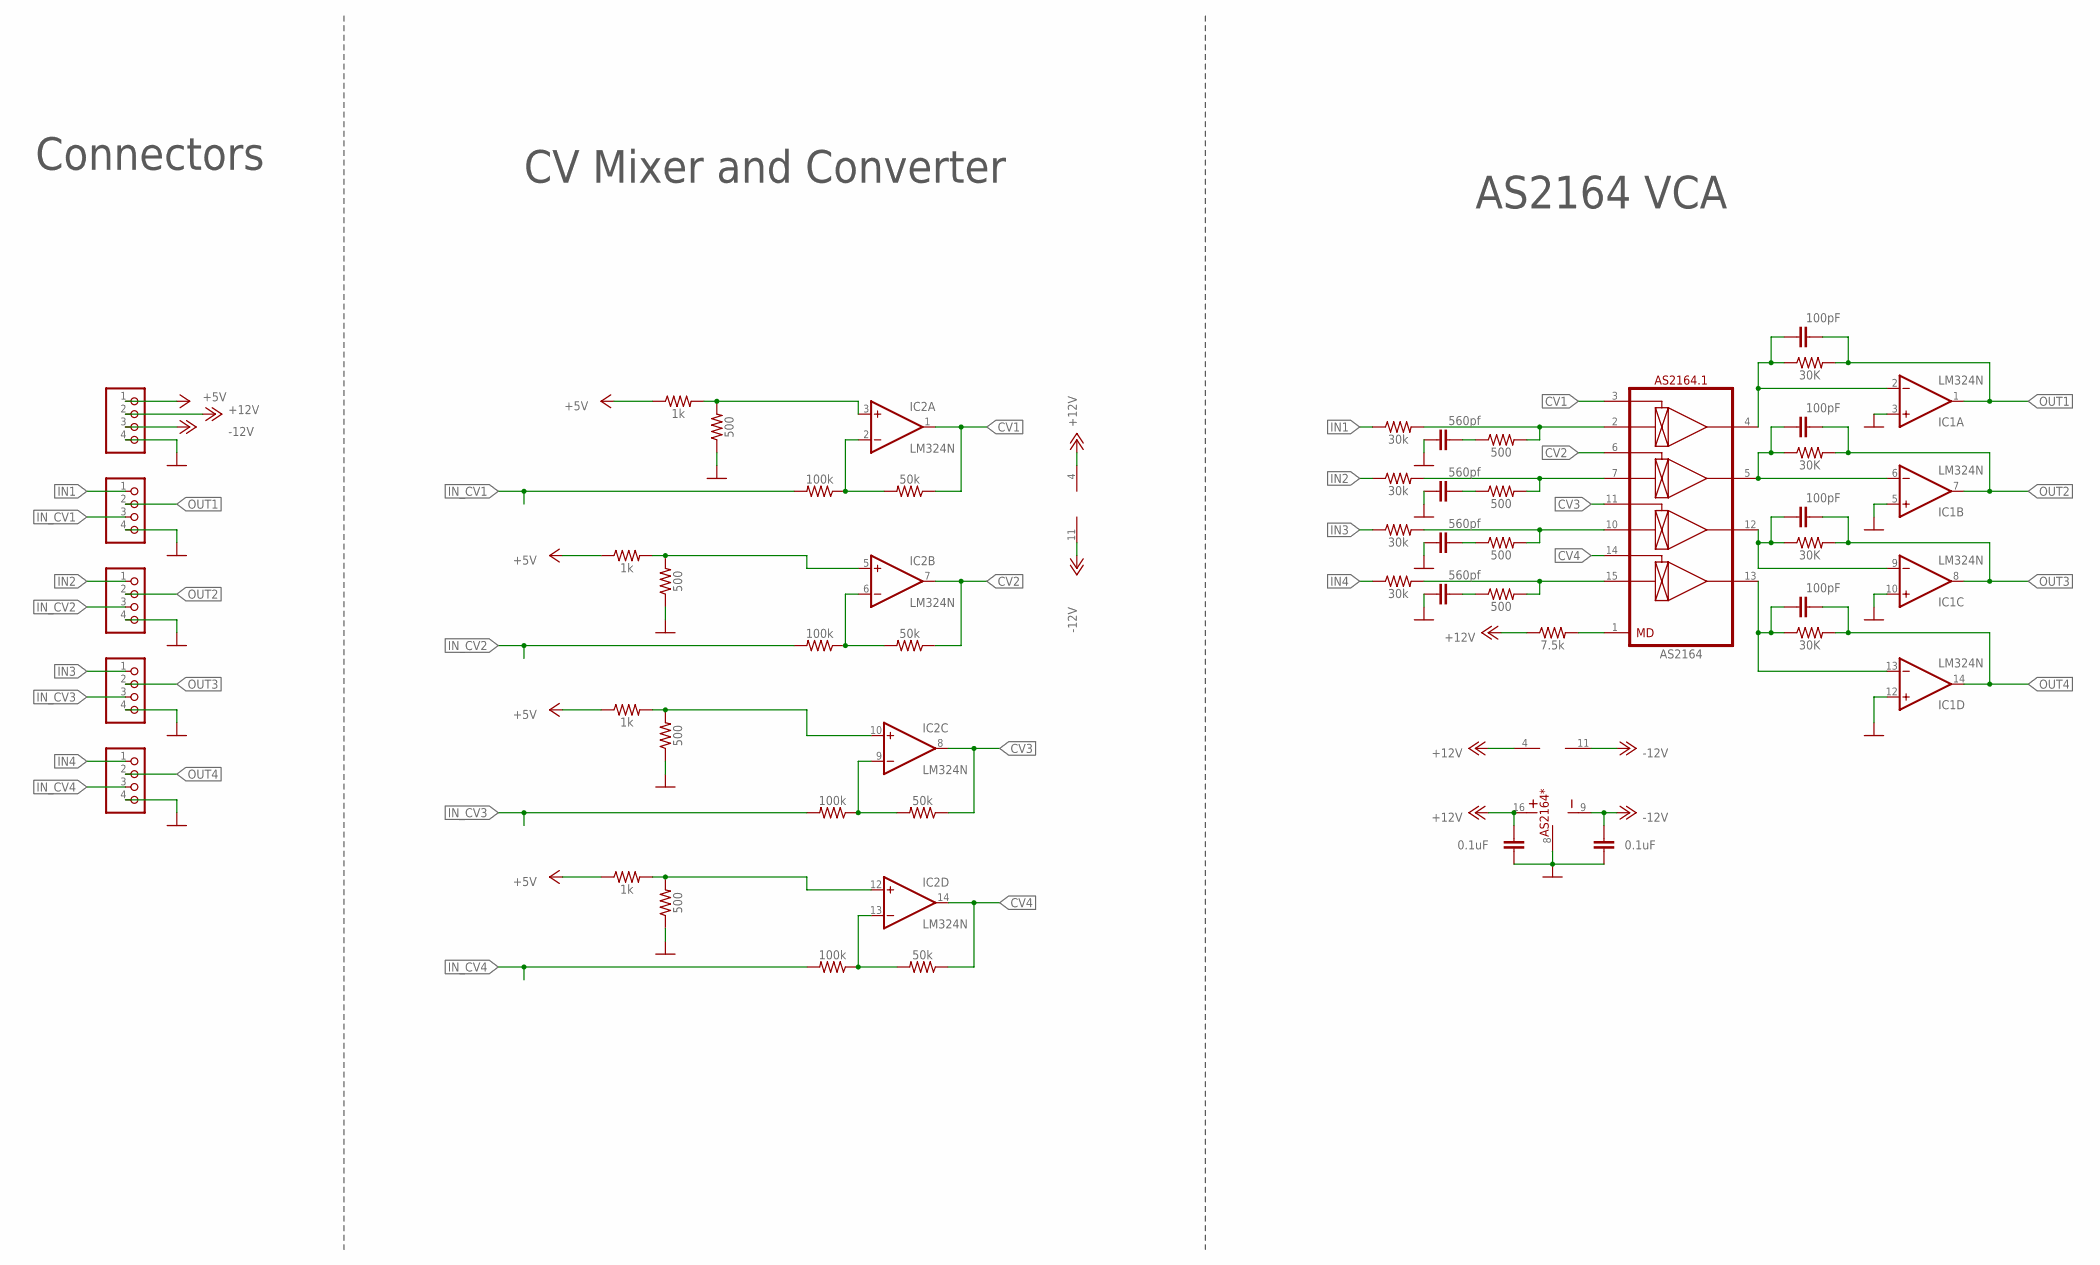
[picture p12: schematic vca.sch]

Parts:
AS2164: AS2164; DIP-16
C1, C2, C3, C4: 560pf; CAP-PTH-SMALL-KIT
C5, C6: 0.1uF; CAP-PTH-SMALL-KIT
C7, C8, C9, C10: 100pF; CAP-PTH-SMALL-KIT
IC1, IC2: LM324N; DIL14
JP1, JP5, JP6, JP7, JP8: PINHD-1X4; 1X04
R1, R2, R3, R5: 30k; AXIAL-0.3
R4, R6, R7, R8, R9, R14, R18, R22: 500; AXIAL-0.3
R10, R13, R17, R21: 1k; AXIAL-0.3
R11, R15, R19, R23: 100k; AXIAL-0.3
R12, R16, R20, R24: 50k; AXIAL-0.3
R25: 7.5k; AXIAL-0.3
R26, R27, R28, R29: 30K; AXIAL-0.3

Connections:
+5V: JP6.1, R10.P$1 (1), R13.P$1 (1), R17.P$1 (1), R21.P$1 (1)
+12V: AS2164.16 (V+), C5.2, IC1.4 (V+), IC2.4 (V+), JP6.2, R25.P$1 (1)
-12V: AS2164.9 (V-), C6.2, IC1.11 (V-), IC2.11 (V-), JP6.3
CV1: AS2164.3 (CV1), IC2.1 (OUT), R20.P$1 (1)
CV2: AS2164.6 (CV2), IC2.7 (OUT), R16.P$1 (1)
CV3: AS2164.11 (CV3), IC2.8 (OUT), R12.P$1 (1)
CV4: AS2164.14 (CV4), IC2.14 (OUT), R24.P$1 (1)
GND: AS2164.8 (GND), C1.1, C2.1, C3.1, C4.1, C5.1, C6.1, IC1.3 (+IN), IC1.5 (+IN), IC1.10 (+IN), IC1.12 (+IN), JP1.4, JP5.4, JP6.4, JP7.4, JP8.4, R9.P$1 (1), R14.P$1 (1), R18.P$1 (1), R22.P$1 (1)
IN1: JP5.1, R1.P$1 (1)
IN2: JP7.1, R2.P$1 (1)
IN3: JP1.1, R3.P$1 (1)
IN4: JP8.1, R5.P$1 (1)
IN_CV1: JP5.3, R19.P$2 (2)
IN_CV2: JP7.3, R15.P$2 (2)
IN_CV3: JP1.3, R11.P$2 (2)
IN_CV4: JP8.3, R23.P$2 (2)
unnamed: AS2164.2 (IN1), R1.P$2 (2), R8.P$2 (2)
unnamed: AS2164.7 (IN2), R2.P$2 (2), R7.P$2 (2)
unnamed: AS2164.10 (IN3), R3.P$2 (2), R6.P$2 (2)
unnamed: AS2164.15 (IN4), R4.P$2 (2), R5.P$2 (2)
unnamed: C1.2, R8.P$1 (1)
unnamed: C2.2, R7.P$1 (1)
unnamed: C3.2, R6.P$1 (1)
unnamed: C4.2, R4.P$1 (1)
unnamed: IC2.5 (+IN), R13.P$2 (2), R14.P$2 (2)
unnamed: IC2.3 (+IN), R9.P$2 (2), R10.P$2 (2)
unnamed: IC2.9 (-IN), R11.P$1 (1), R12.P$2 (2)
unnamed: IC2.10 (+IN), R17.P$2 (2), R18.P$2 (2)
unnamed: IC2.12 (+IN), R21.P$2 (2), R22.P$2 (2)
unnamed: IC2.6 (-IN), R15.P$1 (1), R16.P$2 (2)
unnamed: IC2.2 (-IN), R19.P$1 (1), R20.P$2 (2)
unnamed: IC2.13 (-IN), R23.P$1 (1), R24.P$2 (2)
unnamed: AS2164.1 (MD), R25.P$2 (2)
unnamed: AS2164.13 (OUT4), C7.1, IC1.13 (-IN), R26.P$1 (1)
unnamed: AS2164.12 (OUT3), C8.1, IC1.9 (-IN), R27.P$1 (1)
unnamed: AS2164.5 (OUT2), C9.1, IC1.6 (-IN), R28.P$1 (1)
unnamed: AS2164.4 (OUT1), C10.1, IC1.2 (-IN), R29.P$1 (1)
OUT1: C10.2, IC1.1 (OUT), JP5.2, R29.P$2 (2)
OUT2: C9.2, IC1.7 (OUT), JP7.2, R28.P$2 (2)
OUT3: C8.2, IC1.8 (OUT), JP1.2, R27.P$2 (2)
OUT4: C7.2, IC1.14 (OUT), JP8.2, R26.P$2 (2)

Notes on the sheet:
Connectors
CV Mixer and Converter
AS2164 VCA

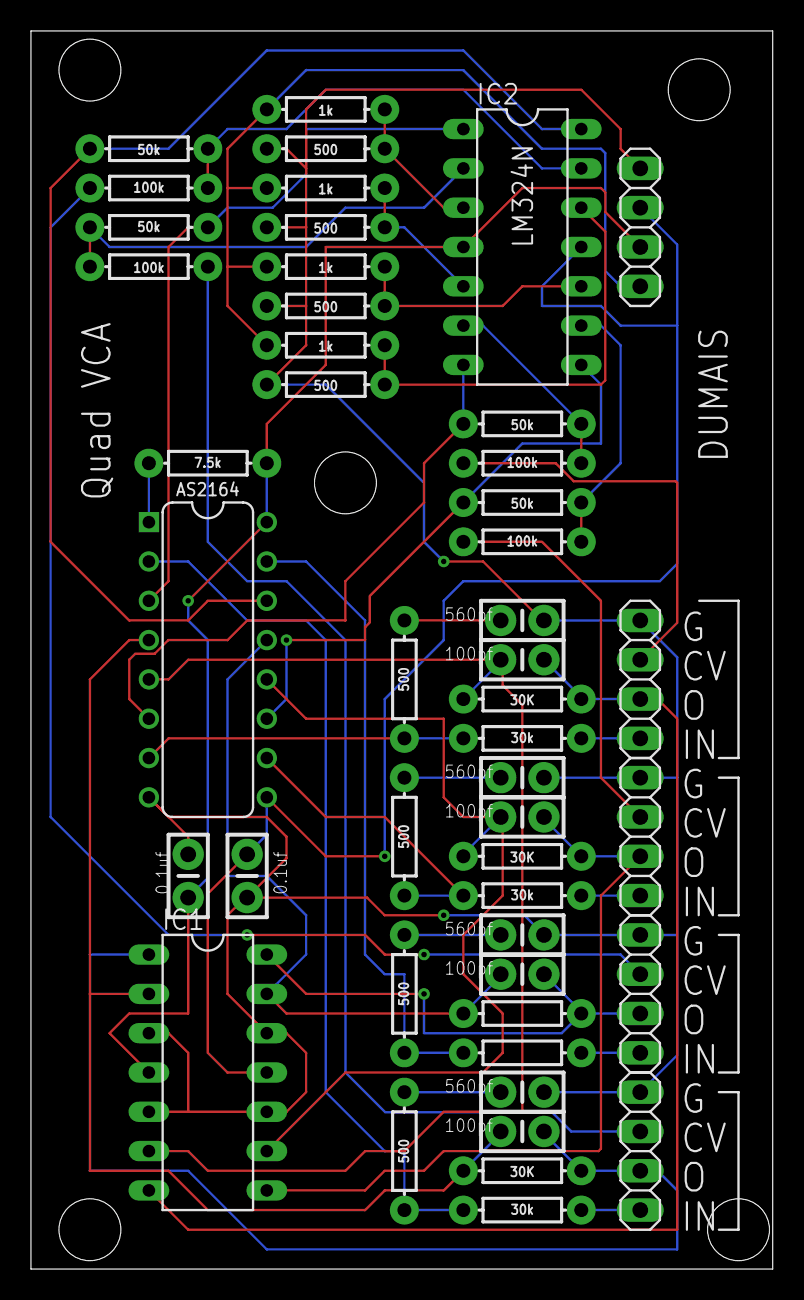
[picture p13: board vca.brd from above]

Board: 2 copper layers, 47.9 x 80.0 mm, 47 parts (0 on the bottom side), 41 nets.

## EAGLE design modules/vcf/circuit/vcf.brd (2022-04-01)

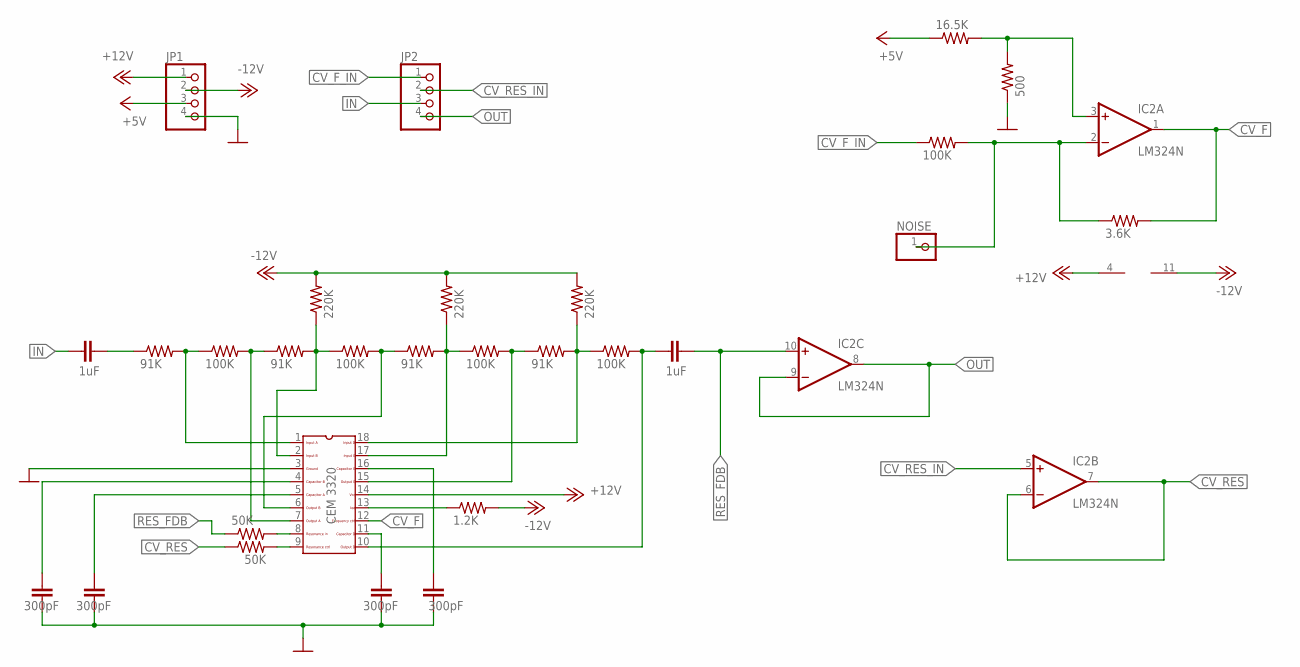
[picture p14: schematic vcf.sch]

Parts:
C1, C2, C3, C4: 300pF; C025-030X050
C5, C6: 1uF; C025-030X050
IC1: CEM3320; DIL18
IC2: LM324N; DIL14
JP1, JP2: PINHD-1X4; 1X04
NOISE: PINHD-1X1; 1X01
R1: 1.2K; 0204/7
R2, R4, R6, R8: 91K; 0204/7
R3, R5, R7, R9, R15: 100K; 0204/7
R10, R11, R12: 220K; 0204/7
R13: 16.5K; 0204/7
R14: 500; 0204/7
R16: 3.6K; 0204/7
R17, R18: 50K; 0204/7

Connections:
+5V: JP1.3, R13.1
+12V: IC1.14, IC2.4 (V+), JP1.1
-12V: IC2.11 (V-), JP1.2, R1.2, R10.2, R11.2, R12.2
CV_F: IC1.12, IC2.1 (OUT), R16.2
CV_F_IN: JP2.1, R15.1
CV_RES: IC2.6 (-IN), IC2.7 (OUT), R18.1
CV_RES_IN: IC2.5 (+IN), JP2.2
GND: C1.2, C2.2, C3.2, C4.2, IC1.3, JP1.4, R14.1
IN: C6.1, JP2.3
unnamed: IC1.13, R1.1
unnamed: C4.1, IC1.4
unnamed: C3.1, IC1.5
unnamed: C1.1, IC1.11
unnamed: C2.1, IC1.16
unnamed: IC1.1, R2.2, R3.1
unnamed: IC1.7, R3.2, R4.1
unnamed: IC1.2, R4.2, R5.1, R11.1
unnamed: IC1.6, R5.2, R6.1
unnamed: IC1.17, R6.2, R7.1, R10.1
unnamed: IC1.15, R7.2, R8.1
unnamed: IC1.18, R8.2, R9.1, R12.1
unnamed: IC2.3 (+IN), R13.2, R14.2
unnamed: C5.1, IC1.10, R9.2
unnamed: IC2.2 (-IN), NOISE.1, R15.2, R16.1
unnamed: C6.2, R2.1
unnamed: IC1.8, R17.2
unnamed: IC1.9, R18.2
OUT: IC2.8 (OUT), IC2.9 (-IN), JP2.4
RES_FDB: C5.2, IC2.10 (+IN), R17.1

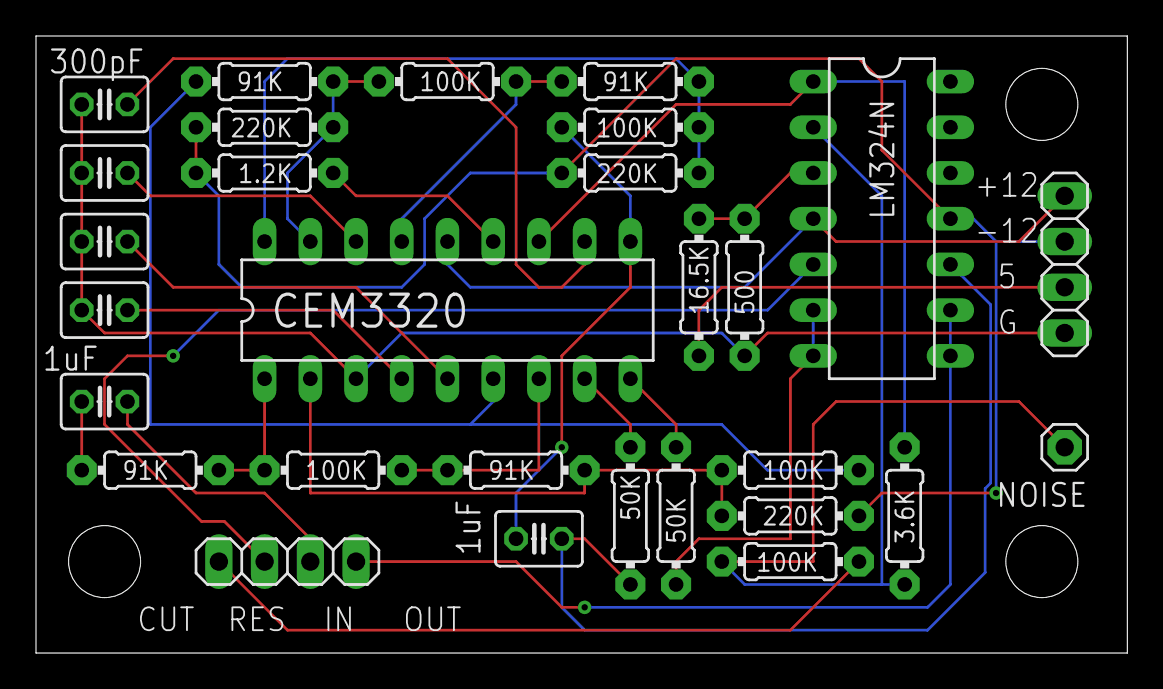
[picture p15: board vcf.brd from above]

Board: 2 copper layers, 60.6 x 34.3 mm, 29 parts (0 on the bottom side), 29 nets.

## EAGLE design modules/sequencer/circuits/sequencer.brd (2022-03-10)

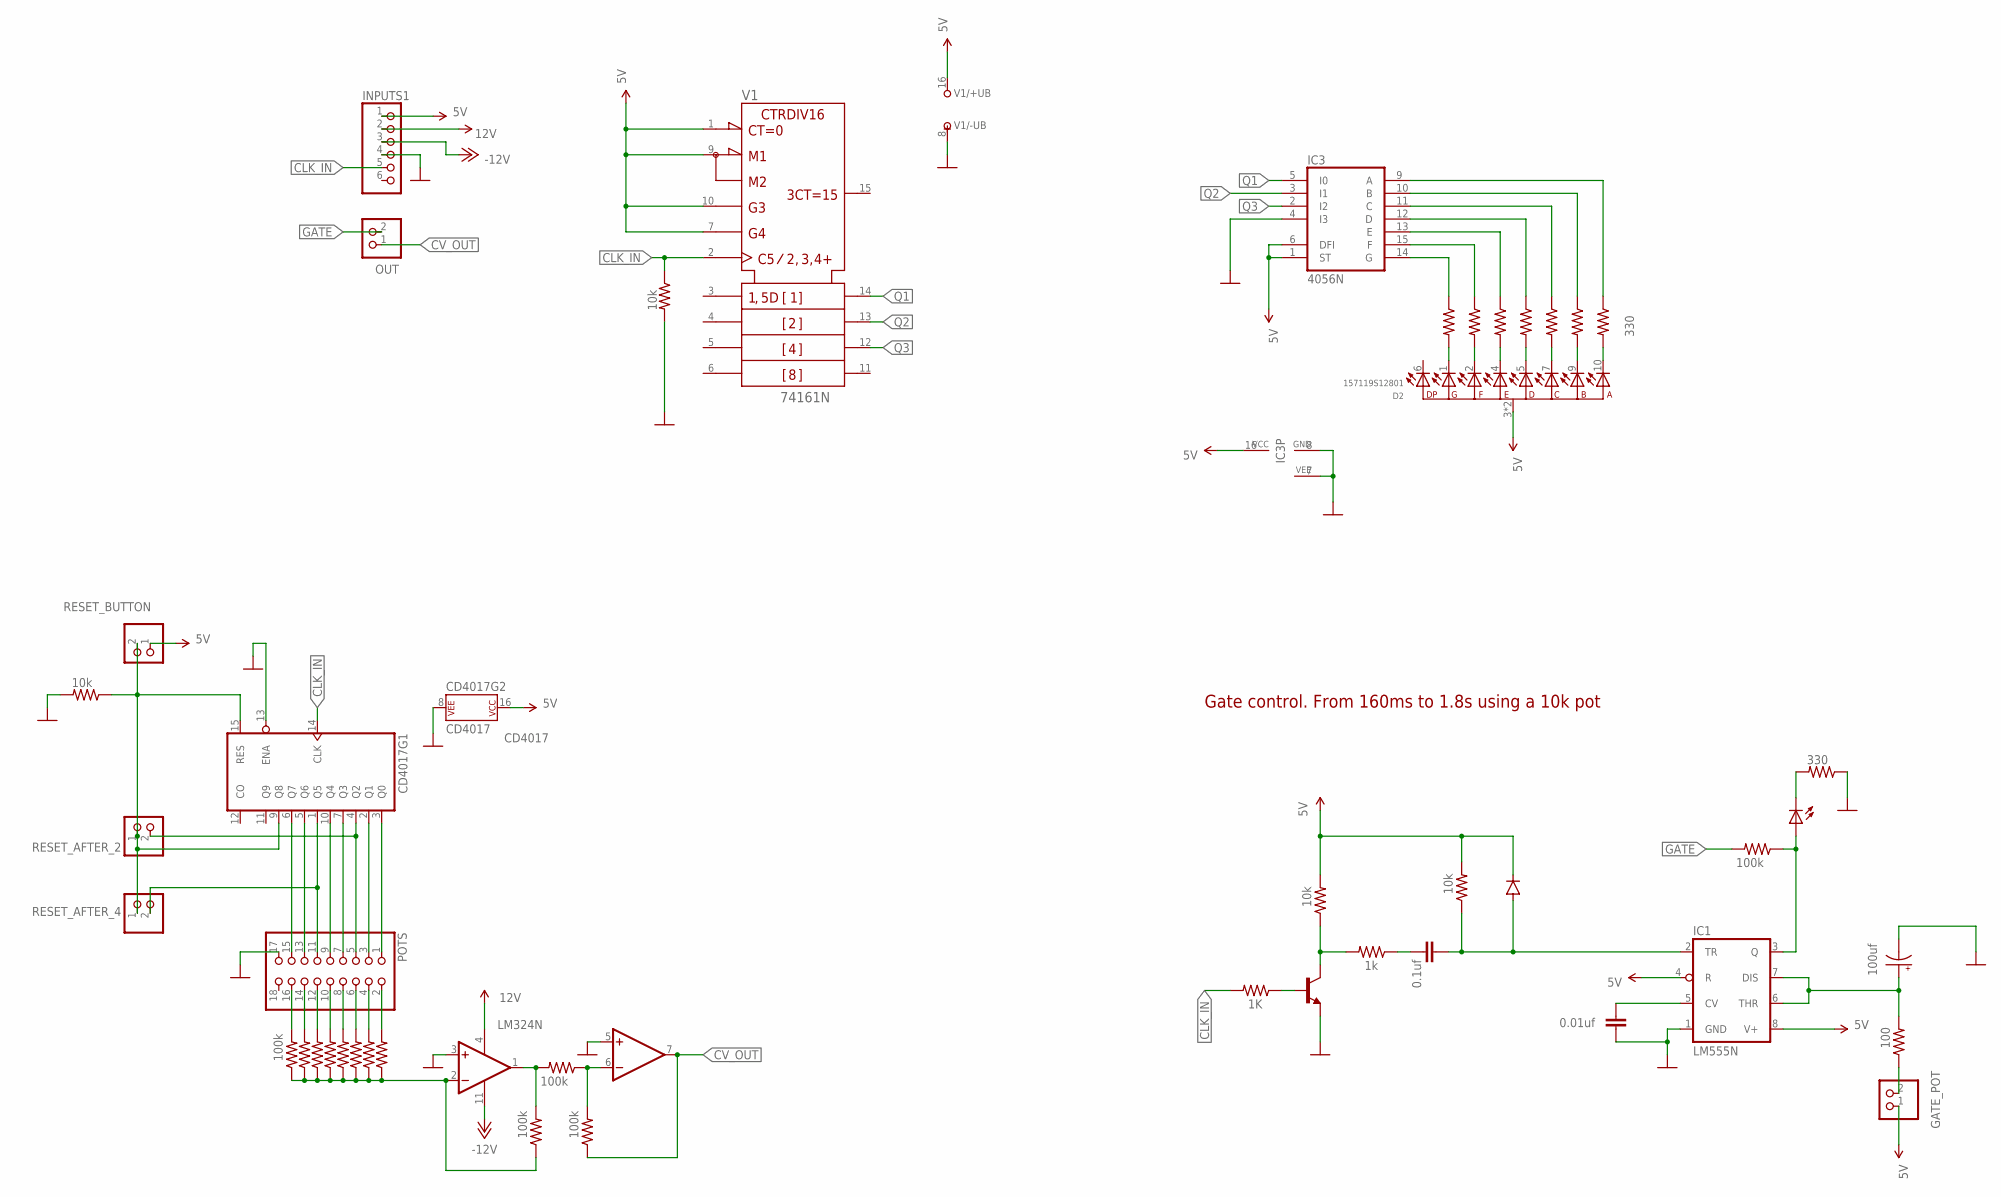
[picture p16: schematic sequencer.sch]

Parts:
1K1: 100k; 0207/12
1K3: 1k; 0207/12
1K4: 10k; 0207/12
2N2: 2N4401-NPN-TO92-EBC; TO92-EBC
C1: 0.01uf; C025-024X044
C3: 100uf; E2,5-6E
C4: 0.1uf; C025-024X044
CD4017: CD4017; DIP16
D1: 1N4004; DO41-10
D2: 157119S12801; WL-T7DS_0.39INCH
GATE_POT: PINHD-1X2; 1X02
IC1: LM555N; DIL08-ROUND
IC2: LM324N; DIL14
IC3: 4056N; DIL16
INPUTS1: PINHD-1X6; 1X06
LED9: LED5MM
OUT: PINHD-1X2; 1X02
POTS: PINHD-2X9; 2X09
R1, R13, R14, R15, R16, R17, R18, R23: 330; 0207/12
R2, R3, R4, R5, R6, R7, R8, R9, R10, R11, R12: 100k; 0207/12
R19: 1K; 0207/12
R20, R22, R24: 10k; 0207/12
R21: 100; 0207/12
RESET_AFTER_2, RESET_AFTER_4: PINHD-1X2; 1X02
RESET_BUTTON: PINHD-1X2; 1X02
V1: 74161N; DIL16

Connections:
5V: 1K4.2, CD4017.16 (P$V+), D1.C, D2.3 (+), D2.8 (+), GATE_POT.1, IC1.4 (R), IC1.8 (V+), IC3.1 (ST), IC3.6 (DFI), IC3.16 (VCC), INPUTS1.1, R20.2, RESET_BUTTON.1, V1.1 (!CLR), V1.7 (ENP), V1.9 (!LOAD), V1.10 (ENT), V1.16 (+UB)
12V: IC2.4 (V+), INPUTS1.2
-12V: IC2.11 (V-), INPUTS1.3
CLK_IN: CD4017.14 (CLK), INPUTS1.5, R19.2, R24.1, V1.2 (CLK)
CV_OUT: IC2.7 (OUT), OUT.1, R11.1
GATE: 1K1.2, OUT.2
GND: 2N2.E, C1.2, C3.-, CD4017.8 (P$V-), CD4017.13 (ENA), IC1.1 (GND), IC2.3 (+IN), IC2.5 (+IN), IC3.4 (I3), IC3.7 (VEE), IC3.8 (GND), INPUTS1.4, POTS.17, R22.2, R23.1, R24.2, V1.8 (-UB)
unnamed: CD4017.9 (Q8), CD4017.15 (RES), R22.1, RESET_AFTER_2.1, RESET_AFTER_4.1, RESET_BUTTON.2
unnamed: 1K3.1, C4.2
unnamed: CD4017.3 (Q0), POTS.1
unnamed: CD4017.2 (Q1), POTS.3
unnamed: CD4017.4 (Q2), POTS.5, RESET_AFTER_2.2
unnamed: CD4017.7 (Q3), POTS.7
unnamed: CD4017.10 (Q4), POTS.9
unnamed: CD4017.1 (Q5), POTS.11, RESET_AFTER_4.2
unnamed: CD4017.5 (Q6), POTS.13
unnamed: CD4017.6 (Q7), POTS.15
unnamed: POTS.2, R3.2
unnamed: POTS.4, R9.2
unnamed: POTS.6, R8.2
unnamed: POTS.8, R7.2
unnamed: POTS.10, R6.2
unnamed: POTS.12, R5.2
unnamed: POTS.14, R4.2
unnamed: POTS.16, R2.2
unnamed: IC2.2 (-IN), R2.1, R3.1, R4.1, R5.1, R6.1, R7.1, R8.1, R9.1, R10.1
unnamed: IC2.1 (OUT), R10.2, R12.2
unnamed: IC2.6 (-IN), R11.2, R12.1
unnamed: IC3.15 (F), R17.1
unnamed: D2.1 (10), R18.2
unnamed: D2.2 (9), R17.2
unnamed: D2.4 (1), R16.2
unnamed: D2.5 (2), R15.2
unnamed: D2.7 (4), R14.2
unnamed: D2.9 (6), R13.2
unnamed: D2.10 (7), R1.2
unnamed: LED9.K (C), R23.2
unnamed: GATE_POT.2, R21.1
unnamed: 1K3.2, 1K4.1, 2N2.C
unnamed: C4.1, D1.A, IC1.2 (TR), R20.1
unnamed: C1.1, IC1.5 (CV)
unnamed: C3.+, IC1.6 (THR), IC1.7 (DIS), R21.2
unnamed: 1K1.1, IC1.3 (Q), LED9.A
unnamed: IC3.9 (A), R1.1
unnamed: IC3.10 (B), R13.1
unnamed: IC3.11 (C), R14.1
unnamed: IC3.12 (D), R15.1
unnamed: IC3.13 (E), R16.1
unnamed: IC3.14 (G), R18.1
unnamed: 2N2.B, R19.1
Q1: IC3.5 (I0), V1.14 (QA)
Q2: IC3.3 (I1), V1.13 (QB)
Q3: IC3.2 (I2), V1.12 (QC)

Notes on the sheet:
Gate control. From 160ms to 1.8s using a 10k pot

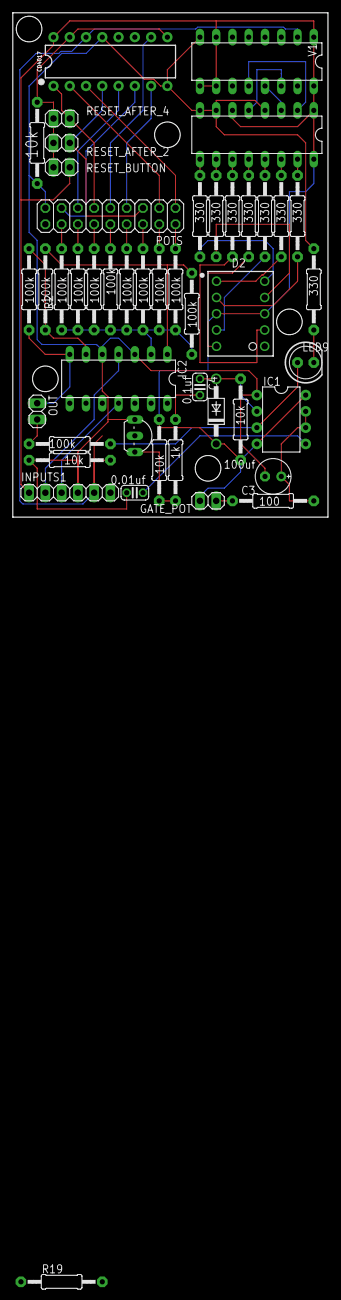
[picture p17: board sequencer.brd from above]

Board: 2 copper layers, 49.2 x 78.7 mm, 46 parts (0 on the bottom side), 53 nets.

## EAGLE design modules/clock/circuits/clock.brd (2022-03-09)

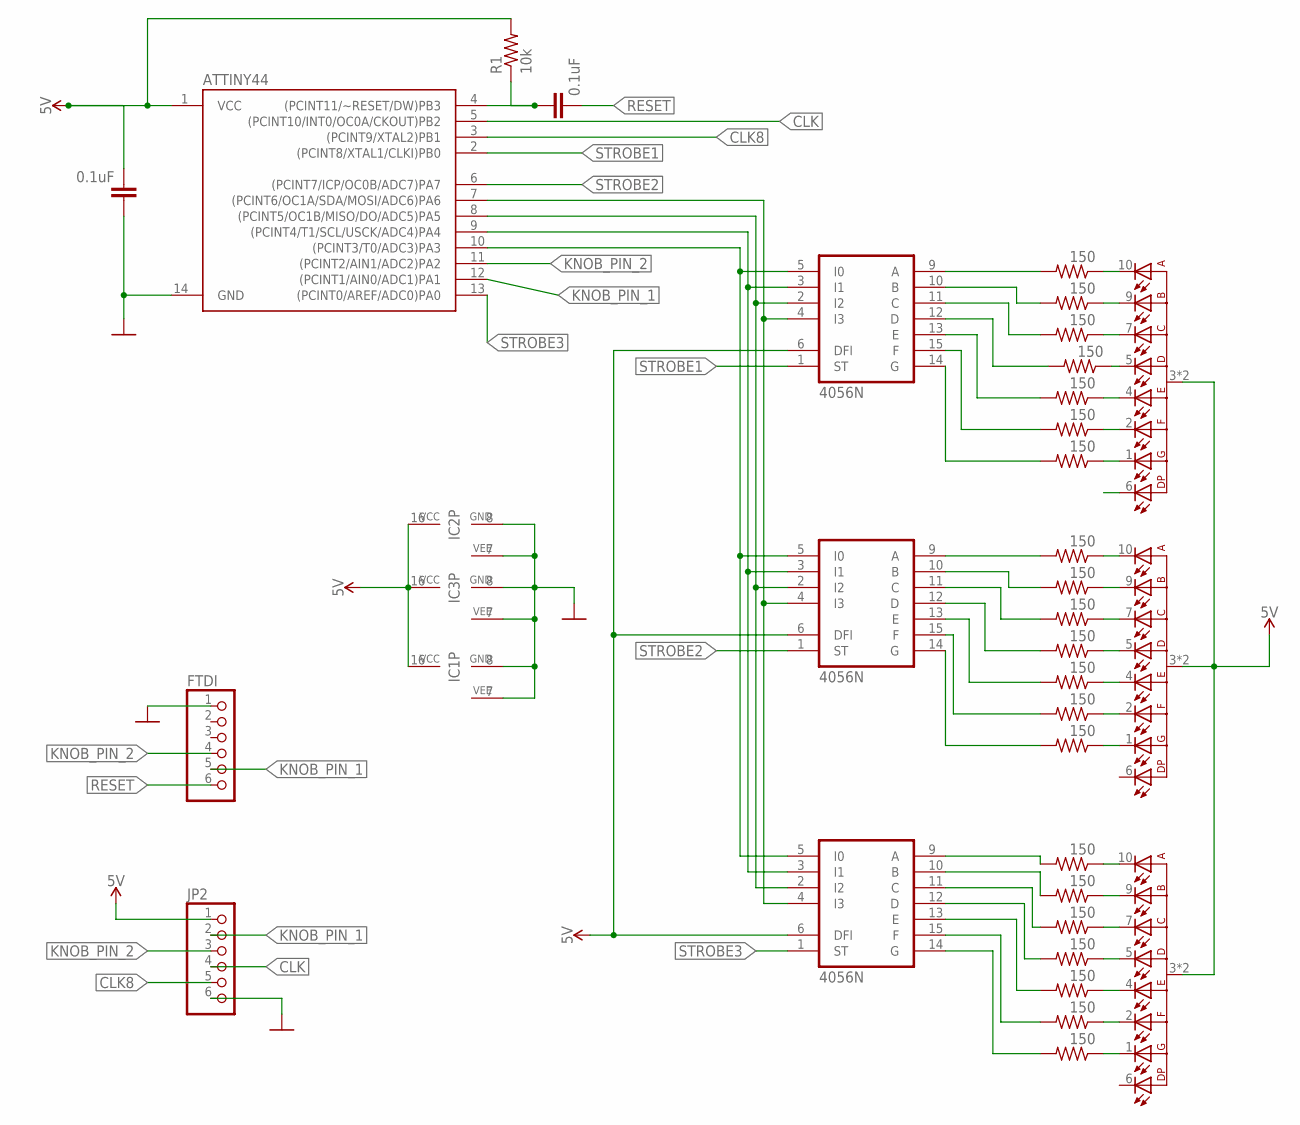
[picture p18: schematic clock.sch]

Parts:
ATTINY44: ATTINY84ATTINY84-20PU; DIP14
C2, C3: 0.1uF; CAP-PTH-SMALL-KIT
D1, D2, D3: 157119S12801; WL-T7DS_0.39INCH
FTDI: PINHD-1X6; 1X06
IC1, IC2, IC3: 4056N; DIL16
JP2: PINHD-1X6; 1X06
R1: 10k; 0207/12
R2, R3, R4, R5, R6, R7, R8, R10, R11, R12, R13, R14, R15, R16, R18, R19, R20, R21, R22, R23, R24: 150; 0207/12

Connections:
5V: ATTINY44.1 (VCC), C3.2, D1.3 (+), D1.8 (+), D2.3 (+), D2.8 (+), D3.3 (+), D3.8 (+), IC1.6 (DFI), IC1.16 (VCC), IC2.6 (DFI), IC2.16 (VCC), IC3.6 (DFI), IC3.16 (VCC), JP2.1, R1.2
CLK: ATTINY44.5 ((PCINT10/INT0/OC0A/CKOUT)PB2), JP2.4
CLK8: ATTINY44.3 ((PCINT9/XTAL2)PB1), JP2.5
GND: ATTINY44.14 (GND), C3.1, FTDI.1, IC1.7 (VEE), IC1.8 (GND), IC2.7 (VEE), IC2.8 (GND), IC3.7 (VEE), IC3.8 (GND), JP2.6
KNOB_PIN_1: ATTINY44.12 ((PCINT1/AIN0/ADC1)PA1), FTDI.5, JP2.2
KNOB_PIN_2: ATTINY44.11 ((PCINT2/AIN1/ADC2)PA2), FTDI.4, JP2.3
unnamed: IC1.9 (A), R18.2
unnamed: ATTINY44.4 ((PCINT11/~RESET/DW)PB3), C2.1, R1.1
unnamed: ATTINY44.10 ((PCINT3/T0/ADC3)PA3), IC1.5 (I0), IC2.5 (I0), IC3.5 (I0)
unnamed: IC1.10 (B), R19.2
unnamed: ATTINY44.9 ((PCINT4/T1/SCL/USCK/ADC4)PA4), IC1.3 (I1), IC2.3 (I1), IC3.3 (I1)
unnamed: ATTINY44.8 ((PCINT5/OC1B/MISO/DO/ADC5)PA5), IC1.2 (I2), IC2.2 (I2), IC3.2 (I2)
unnamed: ATTINY44.7 ((PCINT6/OC1A/SDA/MOSI/ADC6)PA6), IC1.4 (I3), IC2.4 (I3), IC3.4 (I3)
unnamed: IC1.11 (C), R20.2
unnamed: IC1.12 (D), R21.2
unnamed: IC1.13 (E), R22.2
unnamed: IC1.15 (F), R23.2
unnamed: IC1.14 (G), R24.2
unnamed: IC3.14 (G), R16.2
unnamed: IC3.15 (F), R15.2
unnamed: IC3.13 (E), R14.2
unnamed: IC3.12 (D), R13.2
unnamed: IC3.11 (C), R12.2
unnamed: IC3.10 (B), R11.2
unnamed: IC3.9 (A), R10.2
unnamed: IC2.14 (G), R8.2
unnamed: IC2.15 (F), R7.2
unnamed: IC2.13 (E), R6.2
unnamed: IC2.12 (D), R5.2
unnamed: IC2.11 (C), R4.2
unnamed: IC2.10 (B), R3.2
unnamed: IC2.9 (A), R2.2
unnamed: D1.10 (7), R2.1
unnamed: D1.9 (6), R3.1
unnamed: D1.7 (4), R4.1
unnamed: D1.5 (2), R5.1
unnamed: D1.4 (1), R6.1
unnamed: D1.2 (9), R7.1
unnamed: D1.1 (10), R8.1
unnamed: D3.10 (7), R10.1
unnamed: D3.9 (6), R11.1
unnamed: D3.7 (4), R12.1
unnamed: D3.5 (2), R13.1
unnamed: D3.4 (1), R14.1
unnamed: D3.2 (9), R15.1
unnamed: D3.1 (10), R16.1
unnamed: D2.10 (7), R18.1
unnamed: D2.9 (6), R19.1
unnamed: D2.7 (4), R20.1
unnamed: D2.5 (2), R21.1
unnamed: D2.4 (1), R22.1
unnamed: D2.2 (9), R23.1
unnamed: D2.1 (10), R24.1
RESET: C2.2, FTDI.6
STROBE1: ATTINY44.2 ((PCINT8/XTAL1/CLKI)PB0), IC2.1 (ST)
STROBE2: ATTINY44.6 ((PCINT7/ICP/OC0B/ADC7)PA7), IC3.1 (ST)
STROBE3: ATTINY44.13 ((PCINT0/AREF/ADC0)PA0), IC1.1 (ST)

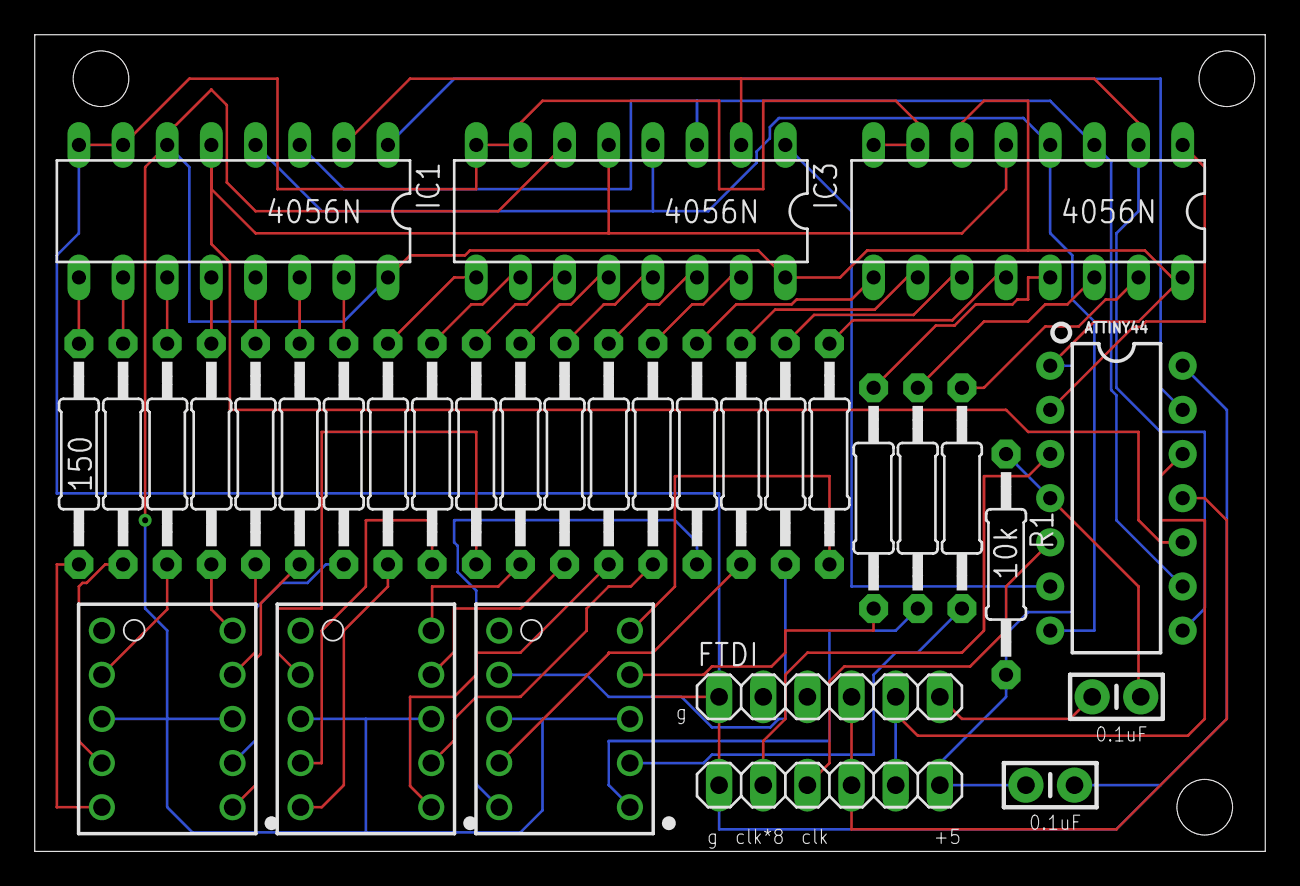
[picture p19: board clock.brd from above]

Board: 2 copper layers, 70.8 x 47.0 mm, 33 parts (0 on the bottom side), 57 nets.

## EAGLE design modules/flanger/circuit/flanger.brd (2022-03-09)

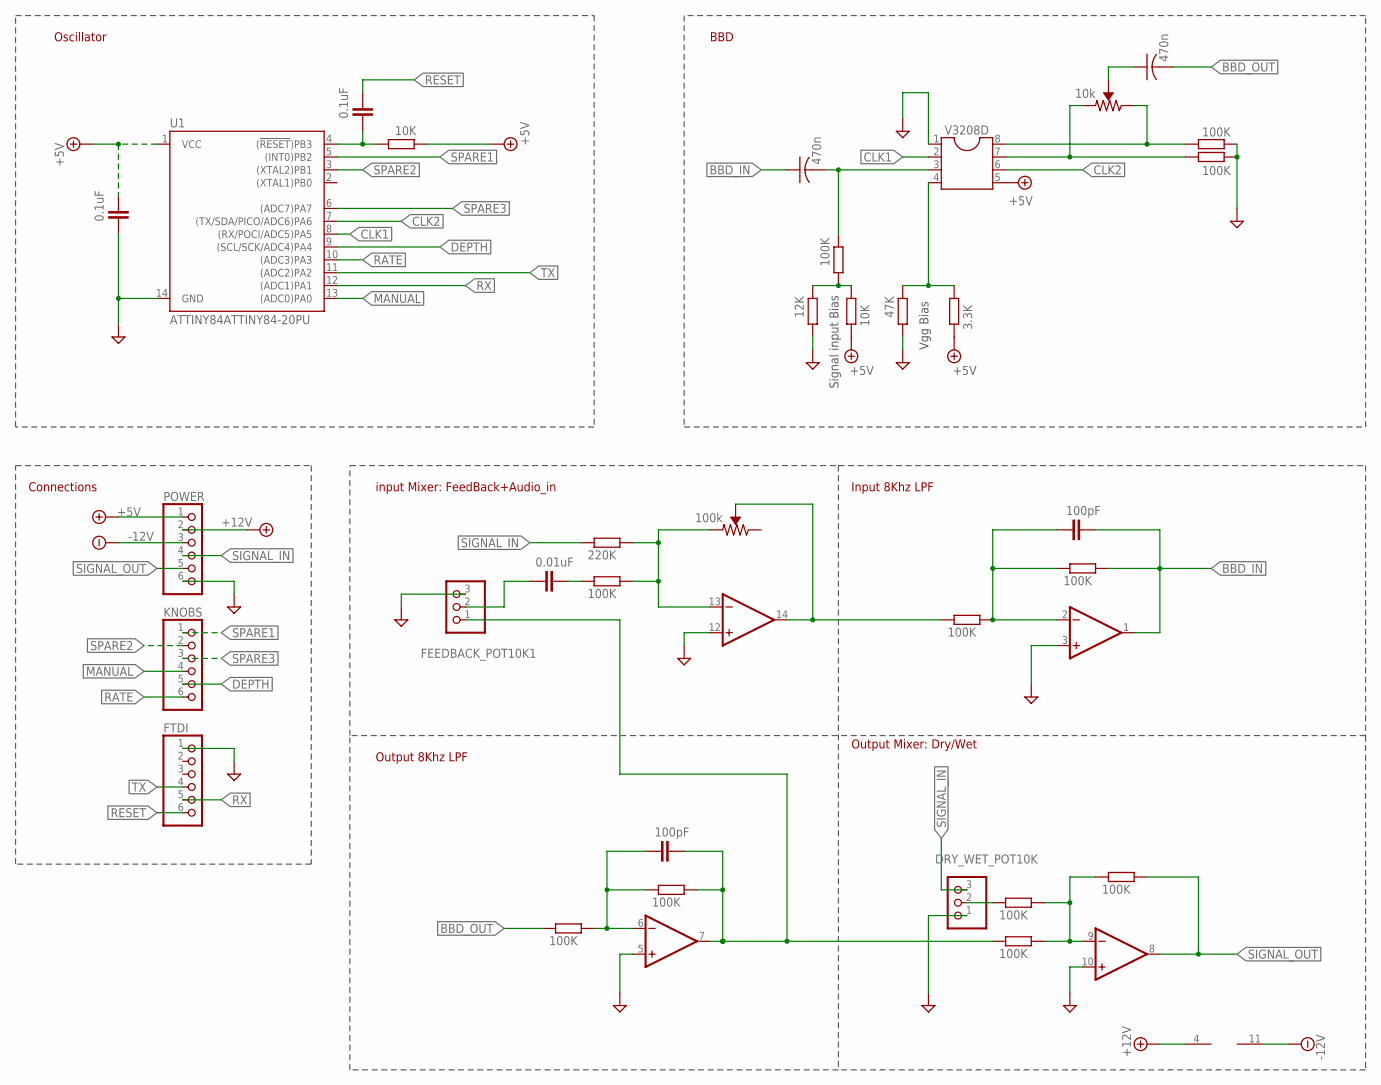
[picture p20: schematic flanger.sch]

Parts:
C1, C2: 470n; C050-025X075
C3, C4: 100pF; C5B2.5
C5: 0.01uF; C5B2.5
C6, C7: 0.1uF; C5B2.5
DRY_WET_POT10K: PINHD-1X3; 1X03
FEEDBACK_POT10K1: PINHD-1X3; 1X03
FTDI: PINHD-1X6; 1X06
IC1: LM324N; DIL14
KNOBS: PINHD-1X6; 1X06
POWER: PINHD-1X6; 1X06
R1: 12K; 0207/10
R2, R6, R7, R8, R9, R10, R11, R13, R14, R16, R17: 100K; 0207/10
R3, R18: 10K; 0207/10
R4: 47K; 0207/10
R5: 3.3K; 0207/10
R15: 220K; 0207/10
U1: ATTINY84ATTINY84-20PU; DIP14
V3208D: DIL8; DIL08
VR1: 10k; TRIMPOT-PTH-3386U
VR2: 100k; TRIMPOT-PTH-3386U

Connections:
+5V: C6.2, POWER.1, R3.2, R5.2, R18.2, U1.1 (VCC), V3208D.5
+12V: IC1.4 (V+), POWER.2
-12V: IC1.11 (V-), POWER.3
BBD_IN: C1.1, C3.2, IC1.1 (OUT), R8.2
BBD_OUT: C2.2, R11.1
CLK1: U1.8 ((RX/POCI/ADC5)PA5), V3208D.2
CLK2: U1.7 ((TX/SDA/PICO/ADC6)PA6), V3208D.6
DEPTH: KNOBS.5, U1.9 ((SCL/SCK/ADC4)PA4)
GND: C6.1, DRY_WET_POT10K.1, FEEDBACK_POT10K1.3, FTDI.1, IC1.3 (+IN), IC1.5 (+IN), IC1.10 (+IN), IC1.12 (+IN), POWER.6, R1.1, R4.1, R6.1, R7.1, U1.14 (GND), V3208D.1
MANUAL: KNOBS.4, U1.13 ((ADC0)PA0)
unnamed: R6.2, V3208D.8, VR1.3 (CW)
unnamed: R7.2, V3208D.7, VR1.1 (CCW)
unnamed: C1.2, R2.2, V3208D.3
unnamed: C2.1, VR1.2 (WIPER)
unnamed: R1.2, R2.1, R3.1
unnamed: R4.2, R5.1, V3208D.4
unnamed: IC1.13 (-IN), R15.2, R16.2, VR2.1 (CCW)
unnamed: C3.1, IC1.2 (-IN), R8.1, R9.2
unnamed: C4.1, IC1.6 (-IN), R10.1, R11.2
unnamed: DRY_WET_POT10K.2, R17.1
unnamed: IC1.14 (OUT), R9.1, VR2.2 (WIPER)
unnamed: C4.2, FEEDBACK_POT10K1.1, IC1.7 (OUT), R10.2, R14.1
unnamed: IC1.9 (-IN), R13.1, R14.2, R17.2
unnamed: C5.2, R16.1
unnamed: C5.1, FEEDBACK_POT10K1.2
unnamed: C7.1, R18.1, U1.4 ((!RESET!)PB3)
RATE: KNOBS.6, U1.10 ((ADC3)PA3)
RESET: C7.2, FTDI.6
RX: FTDI.5, U1.12 ((ADC1)PA1)
SIGNAL_IN: DRY_WET_POT10K.3, POWER.4, R15.1
SIGNAL_OUT: IC1.8 (OUT), POWER.5, R13.2
SPARE1: KNOBS.1, U1.5 ((INT0)PB2)
SPARE2: KNOBS.2, U1.3 ((XTAL2)PB1)
SPARE3: KNOBS.3, U1.6 ((ADC7)PA7)
TX: FTDI.4, U1.11 ((ADC2)PA2)

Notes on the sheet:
Vgg Bias
Signal input Bias
Input 8Khz LPF
Output 8Khz LPF
Output Mixer: Dry/Wet
input Mixer: FeedBack+Audio_in
BBD
Oscillator
Connections

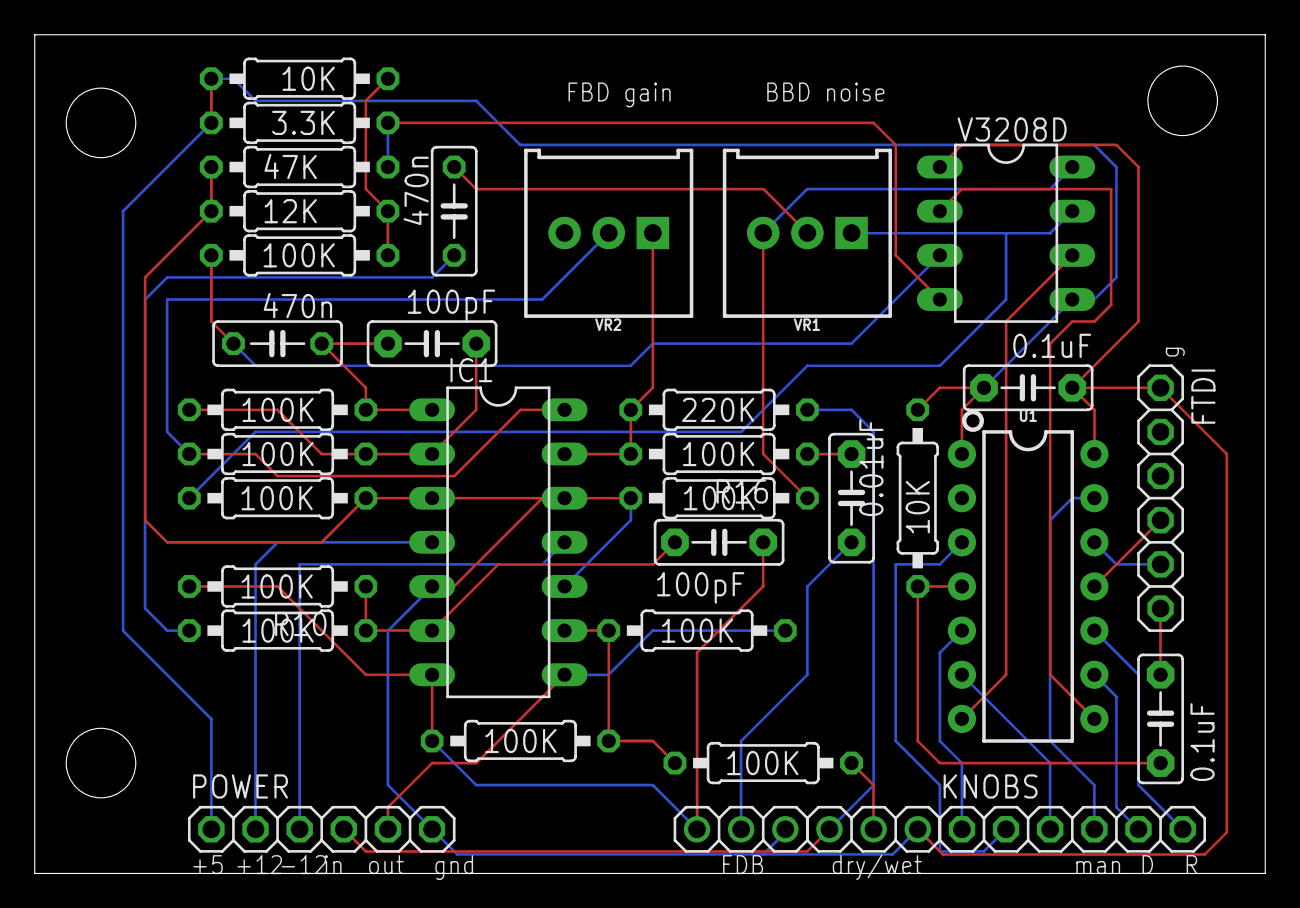
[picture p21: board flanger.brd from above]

Board: 2 copper layers, 70.8 x 48.2 mm, 34 parts (0 on the bottom side), 35 nets.

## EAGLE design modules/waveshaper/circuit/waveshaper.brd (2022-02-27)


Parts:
ATTENUATION: PINHD-1X2; 1X02
C1: 100uf; C025-024X044
C2: 0.1uf; C025-024X044
C3, C4: 33uf; C025-024X044
IC2: LM324N; DIL14
JP1: PINHD-2X4; 2X04
JP2: PINHD-1X1; 1X01
LM7905: 7905T; TO220H
OPTOUT: PINHD-1X2; 1X02
POTS, POTS1, POTS2, POTS3: PINHD-1X2; 1X02
POWER: PINHD-1X4; 1X04
R1: 1K; 0207/12
R2, R3, R4, R5: 100; 0207/12
SIGNAL: PINHD-1X2; 1X02

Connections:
5V: IC2.4 (V+), POWER.3
12V: POWER.2
-5V: C2.2, IC2.11 (V-), LM7905.3 (VO)
-12V: C1.2, LM7905.2 (VI), POWER.1
GND: C1.1, C2.1, IC2.5 (+IN), IC2.10 (+IN), LM7905.1 (GND), POWER.4, R1.2
IN: ATTENUATION.2, IC2.3 (+IN), R1.1
unnamed: ATTENUATION.1, SIGNAL.2
unnamed: C3.1, IC2.6 (-IN), POTS.2, POTS1.1
unnamed: C3.2, IC2.7 (OUT), POTS3.1, R3.2
unnamed: C4.1, IC2.9 (-IN), POTS2.1, R5.2
unnamed: IC2.14 (OUT), OPTOUT.1
unnamed: IC2.13 (-IN), JP1.2
unnamed: IC2.12 (+IN), JP1.1
unnamed: IC2.1 (OUT), IC2.2 (-IN), R2.2
unnamed: POTS.1, R2.1
unnamed: POTS1.2, R3.1
unnamed: POTS2.2, R4.1
unnamed: POTS3.2, R5.1
OUT: C4.2, IC2.8 (OUT), JP2.1, R4.2, SIGNAL.1


Board: 2 copper layers, 55.5 x 33.0 mm, 21 parts (0 on the bottom side), 18 nets.

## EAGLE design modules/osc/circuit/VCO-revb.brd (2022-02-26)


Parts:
C1, C4, C5: 01uf; C025-024X044
C2, C3: 22pf; C025-024X044
FTDI: PINHD-1X6; 1X06
FUTURE: PINHD-1X8BIG; 1X08-BIG
IC1: MEGA1284P; DIL40
LFO1, LFO2, LFO3, LFO4: LED5MM
OUTPUTS: PINHD-1X6; 1X06
PWR, PWR1: PINHD-1X2; 1X02
Q1: 16MHZ; HC49/S
R1: 10K; 0207/12
R2, R3, R4, R5, R6, R7: 1k; 0207/12
STATUS: LED5MM
VCIN: PINHD-1X8; 1X08

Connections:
3.3V: C1.1, C2.1, C3.1, C4.1, FTDI.1, IC1.11 (GND), IC1.31 (GND), LFO1.K (C), LFO2.K (C), LFO3.K (C), LFO4.K (C), PWR.2
LFO1: IC1.4 (AIN1/OC0A/PCINT11), OUTPUTS.3, R4.2
LFO2: IC1.5 (SS/OC0B/PCINT12), OUTPUTS.4, R3.2
LFO3: IC1.6 (MOSI/ICP3/PCINT13), OUTPUTS.5, R2.2
LFO4: IC1.7 (MISO/OC3A/PCINT14), OUTPUTS.6, R5.2
unnamed: LFO1.A, R4.1
unnamed: IC1.40 (ADC0/PCINT0), VCIN.8
unnamed: IC1.39 (ADC1/PCINT1), VCIN.7
unnamed: IC1.38 (ADC2/PCINT2), VCIN.6
unnamed: IC1.37 (ADC3/PCINT3), VCIN.5
unnamed: IC1.36 (ADC4/PCINT4), VCIN.4
unnamed: IC1.35 (ADC5/PCINT5), VCIN.3
unnamed: IC1.34 (ADC6/PCINT6), VCIN.2
unnamed: IC1.33 (ADC7/PCINT7), VCIN.1
unnamed: C3.2, IC1.13 (XTAL1), Q1.2
unnamed: C2.2, IC1.12 (XTAL2), Q1.1
unnamed: LFO2.A, R3.1
unnamed: C4.2, IC1.32 (AREF)
unnamed: C5.2, FTDI.6
unnamed: LFO3.A, R2.1
unnamed: LFO4.A, R5.1
unnamed: OUTPUTS.1, R6.2, R7.2
unnamed: FUTURE.1, IC1.22 (SCL/PCINT16)
unnamed: FUTURE.2, IC1.23 (SDA/PCINT17)
unnamed: FUTURE.3, IC1.24 (TCK/PCINT18)
unnamed: FUTURE.4, IC1.25 (TMS/PCINT19)
unnamed: FUTURE.5, IC1.26 (TDO/PCINT20)
unnamed: FTDI.3, PWR1.1
unnamed: IC1.1 (T0/XCK0/PCINT8), STATUS.K (C)
unnamed: FUTURE.6, IC1.27 (TDI/PCINT21)
unnamed: FUTURE.7, IC1.28 (TOSC1/PCINT22)
unnamed: FUTURE.8, IC1.29 (TOSC2/PCINT23)
OSC1: IC1.8 (SCK/OC3B/PCINT15), R6.1
OSC2: IC1.18 (XCK1/OC1B/PCINT28), R7.1
RESET: C5.1, IC1.9 (RESET), R1.1
RX: FTDI.4, IC1.14 (T3/RXD0/PCINT24)
TX: FTDI.5, IC1.15 (TXD0/PCINT25)
VDD: C1.2, IC1.10 (VCC), IC1.30 (AVCC), PWR.1, PWR1.2, R1.2, STATUS.A


Board: 2 copper layers, 84.8 x 45.7 mm, 25 parts (0 on the bottom side), 38 nets.

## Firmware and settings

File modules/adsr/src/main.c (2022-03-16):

#include <avr/io.h>
 
#define DELAY 5000
#define F_OSC 16000000

// Atack: Time from 0 to 5v output. Time range: 0..4096ms
// Decay: Time from 5v to sustain level. Time range: 0..4096ms
// Sustain: Level from 0 to 5V. This will map 1:! with the S input
// Release: Time from sustain level to 0V. Time range 0..8192ms

#define A_PIN 0
#define D_PIN 1
#define S_PIN 2
#define R_PIN 3
#define GATE_PIN 3 // PD2

#define STATE_IDLE 0
#define STATE_ATTACK 1
#define STATE_DECAY 2
#define STATE_SUSTAIN 3
#define STATE_RELEASE 4

uint16_t adcs[5];

void spi_init()
{
}

void timer_init()
{
    TCNT0 = 0;
    OCR0A = 250;    // This will yield a tick  1000 times per second
    TCCR0A = 1<<WGM01; // CTC
    TCCR0B = (1 << CS01) | (1<< CS00); // divided by 64: 250000 times per second
    TIFR0 = 0;
    TIMSK0 |= 0b10;
}

void dac_write(uint16_t val)
{
    uint8_t dh = 0b00110000 | (val >> 8L);
    uint8_t dl = val & 0xFF;

    PORTB &= !(1<<2);
    SPDR = dh;              
    while(!(SPSR & (1 << SPIF)));
    SPDR = dl;           
    while(!(SPSR & (1 << SPIF)));
    PORTB |= (1<<2);
}

void adc_init() {
    ADMUX = (1 << REFS0) | (0 << ADLAR); // AVcc with capacitor to ARef
    ADCSRA |= (1 << ADPS0) | (1 << ADPS2) | (1 << ADPS1) | (1 << ADEN) | (1<<ADSC);
}
 
void adc_read() {
    if (!(ADCSRA & (1 << ADIF))) return;
 
    uint8_t admux = ADMUX;
    uint8_t index = admux & 0b00111;
    uint8_t l = ADCL;
    uint8_t h = ADCH;
    ADMUX = (admux & 0b11100000) | ((index+1) & 0b00011);
    ADCSRA |= (1 << ADIF) | (1<<ADSC); // Clear ADIF by writing 1 in it, and start a new conversion
    uint16_t temp = ((h<<8L)|l);
 
    // Convert to 12bit values 
    adcs[index] = (temp<<2L);
}

int main (void)
{
    DDRD = 0xF0;
    DDRC = 0x00;
    DDRB = (1<<3)|(1<<5)|(1<<2); // SPI

    timer_init();
    spi_init();
    adc_init();

    uint8_t state= STATE_IDLE;
    uint8_t gate_status = 0;
    uint8_t temp_gate_status = 0;
    uint16_t debounce=0;

    // Level will be calculated using 15bits and then sized down to 12. This is
    // so that we can have a better granularity on the rate of change
    uint16_t level = 0;

    SPCR = (1<<SPE) | (1<<MSTR) | (1<<SPR0);
    dac_write(0xFFF);


    uint8_t flash_ms_delay = 127;
    uint16_t ms_count = 0;
    while (1)
    {
        // Debounce gate pin
        uint8_t n = !(PIND & (1<< GATE_PIN));
        if (n != gate_status)
        {
            temp_gate_status = n;
            debounce = 1000L;
        }
        if (debounce >0) debounce--;

        // Check if pin has been steady for a while and its state has changed
        if (debounce == 1 && temp_gate_status != gate_status)
        {
            gate_status = temp_gate_status;

            if (!gate_status) // Gate is released 
            {
                if (state != STATE_IDLE) 
                {
                    state = STATE_RELEASE;
                    ms_count=0;
                    PORTD = 0b11110000; 
                }
            }
            else
            {
                // Move to Attack state
                state = STATE_ATTACK;
                ms_count = 0;
                level = 0;
            }
        }

        adc_read();

        if (TIFR0 & (1<<OCF0A)) // This will be true every 1ms
        {
            TIFR0 |= (1<<OCF0A);
            ms_count++;
            flash_ms_delay = (flash_ms_delay -1)&0x7F;

            if (state == STATE_ATTACK)
            {
                PORTD = 0b01110000; // Steady Blue LED
                uint16_t delta_level = 0x7FFFL-level; 
                uint16_t delta_time = (adcs[A_PIN]>ms_count)?adcs[A_PIN]-ms_count:1;
                uint16_t rate = delta_level/delta_time; 
                level += rate;
                if (level >= 0x7FFFL) level=0x7FFFL;
                

                if (ms_count >= adcs[A_PIN] || level == 0x7FFFL) {
                    state = STATE_DECAY;
                    ms_count=0;
                }
            }
            else if (state == STATE_DECAY)
            {
                PORTD = 0b10110000; // Steady yellow LED
                uint16_t s = adcs[S_PIN] << 3L;
                uint16_t delta_level = (s<level)?level-s:0; 
                uint16_t delta_time = (adcs[D_PIN]>ms_count)?adcs[D_PIN]-ms_count:1;
                uint16_t rate = delta_level/delta_time; 
                if (level > rate) level-=rate; else level = 0;
    
                if (ms_count >= adcs[D_PIN]) {
                    state = STATE_SUSTAIN;
                    ms_count=0;
                }
            }
            else if (state == STATE_SUSTAIN)
            {
                PORTD = 0b11010000; // Steady green LED
                level = adcs[S_PIN]<<3L; // to 15bit level
                ms_count=0;
            }
            else if (state == STATE_RELEASE)
            {
                if (flash_ms_delay == 0) PIND = 0b10000000; // Flashing Blue LED
                uint16_t r = adcs[R_PIN] << 2L; // Multiply range by 4 since we want 0..2^14
                uint16_t delta_level = level; 
                uint16_t delta_time = (r>ms_count)?r-ms_count:1;
                if (delta_level == 0) delta_level = 0;
                uint16_t rate = delta_level/delta_time;
                if (level > rate) level-=rate; else level = 0;

                if (ms_count >= r || level ==0)
                {
                    state = STATE_IDLE;
                    ms_count=0;
                }
            }
            else if (state == STATE_IDLE)
            {
                PORTD = 0b11100000; // Steady red LED
                level = 0;
            }

            dac_write(level>>3L);
        }
        
    }
}

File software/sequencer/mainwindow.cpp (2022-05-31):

#include "mainwindow.h"
#include "ui_mainwindow.h"

#include <QSpacerItem>
#include <QInputDialog>
#include "MidiFileUtil.h"
#include "MidiRoll.h"
#include <QFileDialog>
#include <QDir>

#define MAX_TRACKS 16

MainWindow::MainWindow(QWidget *parent)
    : QMainWindow(parent)
    , ui(new Ui::MainWindow)
{

    ui->setupUi(this);
    for (int i = 0; i<MAX_TRACKS; i++)
    {
        TrackWidget *tw = new TrackWidget();
        this->ui->frame_4->layout()->addWidget(tw);
        tw->setLabel("Track " + QString::number(i));
        this->trackWidgets.append(tw);
        connect(tw, &TrackWidget::trackSelected, this, &MainWindow::on_track_selected);
    }

    this->zoomx = 1;
    this->zoomy = 1;
    this->defaultChannel = 0;

    this->timer = new QTimer(this);
    connect(this->timer, &QTimer::timeout, this, &MainWindow::processTimer);

    this->sequencer = new Sequencer();



    MidiRoll *mr = ui->midiRoll;
    if (QCoreApplication::arguments().size()>1)
    {
        this->loadFile(QCoreApplication::arguments().at(1).toStdString());
    }
    this->ui->midiRoll->resetMatrix();
    this->ui->midiRoll->scale(this->zoomx, this->zoomy);

    this->setBPM(120);

    connect(mr, &MidiRoll::onRowHover, this, &MainWindow::on_midiRoll_row_hover);
    connect(mr, &MidiRoll::onNewBlock, this, &MainWindow::on_midiRoll_NewBlock);
    connect(mr, &MidiRoll::onBlockRemoved, this, &MainWindow::on_midiRoll_BlockRemoved);
    connect(mr, &MidiRoll::onBlocksMoved, this, &MainWindow::on_midiroll_BlocksMoved);

    this->noteStatusLabel = new QLabel();
    this->ui->statusbar->addWidget(this->noteStatusLabel);
    this->modeLabel = new QLabel();
    this->ui->statusbar->addWidget(this->modeLabel);



}

void MainWindow::loadFile(std::string fname)
{
    this->sequencer->reset();
    MidiRoll *mr = ui->midiRoll;
    MidiFileUtil mf(fname);
    auto midiFileEvents = mf.getEventsFromFile();

    int i = 0;
    for (auto trk : midiFileEvents)
    {
        this->sequencer->loadEvents(i, trk);
        i++;
    }
    mr->setTicksPerQuarterNotes(mf.getTicksPerQuarteNotes());
    sequencer->setTicksPerQuarterNote(mf.getTicksPerQuarteNotes());
    this->changeTrack(0);

    mr->setCursorPosition(2*mf.getTicksPerQuarteNotes());
}

MainWindow::~MainWindow()
{
    delete ui;
    delete this->sequencer;
    for (auto tw : this->trackWidgets) delete tw;
}

void MainWindow::processTimer()
{
    QRect section = this->ui->midiRoll->getSection();
    if (this->sequencer->getCurrentTick() > (section.width()+section.x()))
    {
        this->sequencer->setPosition(section.x());
    }

    this->sequencer->onClockTick();

    ui->midiRoll->setCursorPosition(this->sequencer->getCurrentTick());
}

void MainWindow::setBPM(int bpm)
{
    this->timer->start((1000/(bpm/60))/this->sequencer->getTicksPerQuarterNote());
}

void MainWindow::changeTrack(int trk)
{
    this->sequencer->setTrack(trk);

    MidiRoll *mr = ui->midiRoll;
    QVector<MidiRollEvent*> el;

    for (auto mev : this->sequencer->dumpEvents())
    {
        for (auto ev : mev.second)
        {
            if (ev->event == 0x90)
            {
                el.append(new MidiRollEvent(ev->start, ev->duration, ev->channel, ev->d1));
            }
        }
    }
    mr->setEvents(el);

    for (int i = 0; i<MAX_TRACKS; i++)
    {
        this->trackWidgets[i]->setActive(i==trk);
    }
}


void MainWindow::saveMidiFile(std::string fname)
{
    std::vector<std::map<long, std::vector<MidiEvent*>>> tracks;
    for (int i = 0; i < MAX_TRACKS; i++)
    {
        auto trk = this->sequencer->dumpEvents(i);
        if (trk.size() == 0) continue;

        tracks.push_back(trk);
    }
    MidiFileUtil::saveToFile(fname, tracks, this->sequencer->getTicksPerQuarterNote());

}

void MainWindow::on_comboBox_currentIndexChanged(int index)
{
    this->defaultChannel = index;
}


void MainWindow::on_spinBox_valueChanged(int arg1)
{
    this->setBPM(arg1);
}

void MainWindow::on_horizontalSlider_valueChanged(int value)
{
    this->zoomx = ((float)value/100.0);
    this->ui->midiRoll->resetMatrix();
    this->ui->midiRoll->scale(this->zoomx, this->zoomy);
}

void MainWindow::on_verticalSlider_valueChanged(int value)
{
    this->zoomy = ((float)value/100.0);
    this->ui->midiRoll->resetMatrix();
    this->ui->midiRoll->scale(this->zoomx, this->zoomy);
}

void MainWindow::on_midiRoll_row_hover(int row)
{
    this->noteStatusLabel->setNum(row);
}

void MainWindow::on_midiRoll_NewBlock(int tick, int row, int length)
{
    this->ui->midiRoll->addEvent(new MidiRollEvent(tick, length, this->defaultChannel, row));

    MidiEvent *ev = new MidiEvent();
    ev->start = tick;
    ev->duration = length;
    ev->channel = this->defaultChannel;
    ev->event = 0x90;
    ev->d1 = row;
    ev->d2 = 127;
    this->sequencer->addEvent(tick, ev);

}


void MainWindow::on_actionEdit_2_triggered() // Play
{
    this->sequencer->play();
}

void MainWindow::on_actionEdit_3_triggered() // Set Edit Mode
{
    this->ui->midiRoll->setMouseMode(MidiRoll::MouseMode::Edit);
    this->modeLabel->setText("Editing");
}

void MainWindow::on_actionSelect_triggered() // Set Select Mode
{
    this->ui->midiRoll->setMouseMode(MidiRoll::MouseMode::Select);
    this->modeLabel->setText("Selecting");
}

void MainWindow::on_actionStop_triggered()
{
    this->sequencer->stop();
}

void MainWindow::on_actionDelete_triggered()
{
    this->ui->midiRoll->deleteSelection();
}

void MainWindow::on_midiRoll_BlockRemoved(MidiRollEvent* ev)
{
    this->sequencer->removeEvent(ev->start, ev->channel, ev->note);

}

void MainWindow::on_track_selected(TrackWidget* track)
{
    if (track->isActive()) return; // Don't change if it's the same track

    int i = 0;
    while (i < this->trackWidgets.size())
    {
        if (this->trackWidgets[i] == track)
        {
            this->on_actionStop_triggered();
            this->changeTrack(i);
            return;
        }
        i++;
    }
}

void MainWindow::showDevicesDialog()
{
    auto devs = this->sequencer->getMidi()->listDevices();
    QStringList items;
    for (std::string d : devs) items << QString(d.c_str());

    bool ok;
    QString item = QInputDialog::getItem(this, "Midi Devices", "Device", items, 0, false, &ok);

    if (!ok) return;

    int index = items.indexOf(item);
    this->sequencer->getMidi()->useDevice(index);
    //TODO: display device name on status bar
}

void MainWindow::on_midiroll_BlocksMoved(std::vector<MidiRollEvent*> originals, std::vector<MidiRollEvent*> changed)
{
    for (int i = 0; i < originals.size(); i++)
    {
        auto o = originals[i];
        auto c = changed[i];
        this->ui->midiRoll->updateEvent(o, c);

        MidiEvent evo(o->start, o->length, o->channel, 0x90, o->note, 0);
        MidiEvent evc(c->start, c->length, c->channel, 0x90, c->note, 0);
        this->sequencer->updateEvent(&evo, &evc);
    }
}
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

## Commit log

2022-01-30 circuits changes
    [VCO.brd, VCO.sch]
2022-02-02 Adding circuits
    [digipots.brd, digipots.sch, sequencer.brd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]
2022-02-02 digipots CV
    [digipots.brd, digipots.sch]
2022-02-03 sequencer design
    [sequencer.brd, sequencer.sch]
2022-02-05 Sequencer design complete
    [sequencer.brd, sequencer.sch]
2022-02-06 adding clock module
    [clock.brd, clock.sch, divider.brd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]
2022-02-08 PCB correction for clock
    [clock.brd, clock.sch]
2022-02-10 Seq board
    [sequencer.brd, sequencer.sch]
2022-02-11 Adding counter to seq
    [sequencer.brd, sequencer.sch]
2022-02-12 VCA design
    [calculations.ods, vca.brd, vca.sch]
2022-02-12 Resistor changes for vca
    [calculations.ods, vca.brd, vca.sch]
2022-02-13 schematic for midi2cv
    [midi2cv.brd, midi2cv.sch]
2022-02-14 midi2cv board
    [midi2cv.brd, midi2cv.sch]
2022-02-15 sequencer board
    [sequencer.brd, sequencer.sch]
2022-02-18 adsr board
    [adsr.sch, uni2bi.brd]
2022-02-18 adsr and drum
    [partitions.csv]
2022-02-21 vca changes
    [calculations.ods, vca.brd, vca.sch]
2022-02-21 modified VCA
    [vca.brd, vca.sch]
2022-02-21 vco rev b
    [VCO-revb.brd, VCO-revb.sch]
2022-02-21 Finished VCA
    [vca.brd]
2022-02-23 Adding VCF circuit
    [vcf.brd, vcf.sch]
2022-02-26 vcf done
    [VCO-revb.brd, VCO-revb.sch, vcf.brd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]
2022-02-27 Adding resistors before each pots on wavshapper to avoid shorting when pot is at 0%
    [waveshaper.brd, waveshaper.sch]
2022-03-10 Sequencer fixes
    [partitions.csv, sequencer.brd, sequencer.sch]
2022-03-16 Noise firmware. ADSR and midi2CV fixes
    [main.c, timer.c]
2022-03-19 Started Drum circuit
    [drums.sch]
2022-04-01 a few misc changes
    [drums.brd, drums.sch, vca.brd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]
2022-04-05 drum board
    [drums.brd, drums.sch]
2022-04-05 drum board cleanup
    [drums.brd, drums.sch]
2022-04-07 drum machine
    [drums.brd, drums.sch]
2022-04-18 long overdue commit
    [drums.brd, drums.sch]

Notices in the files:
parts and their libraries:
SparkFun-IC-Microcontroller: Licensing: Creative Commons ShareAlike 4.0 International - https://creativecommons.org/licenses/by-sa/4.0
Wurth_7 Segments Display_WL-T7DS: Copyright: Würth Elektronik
